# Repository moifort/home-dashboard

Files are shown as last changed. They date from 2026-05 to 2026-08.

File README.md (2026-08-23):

# Home Assistant e-Paper Dashboard

<p align="center">
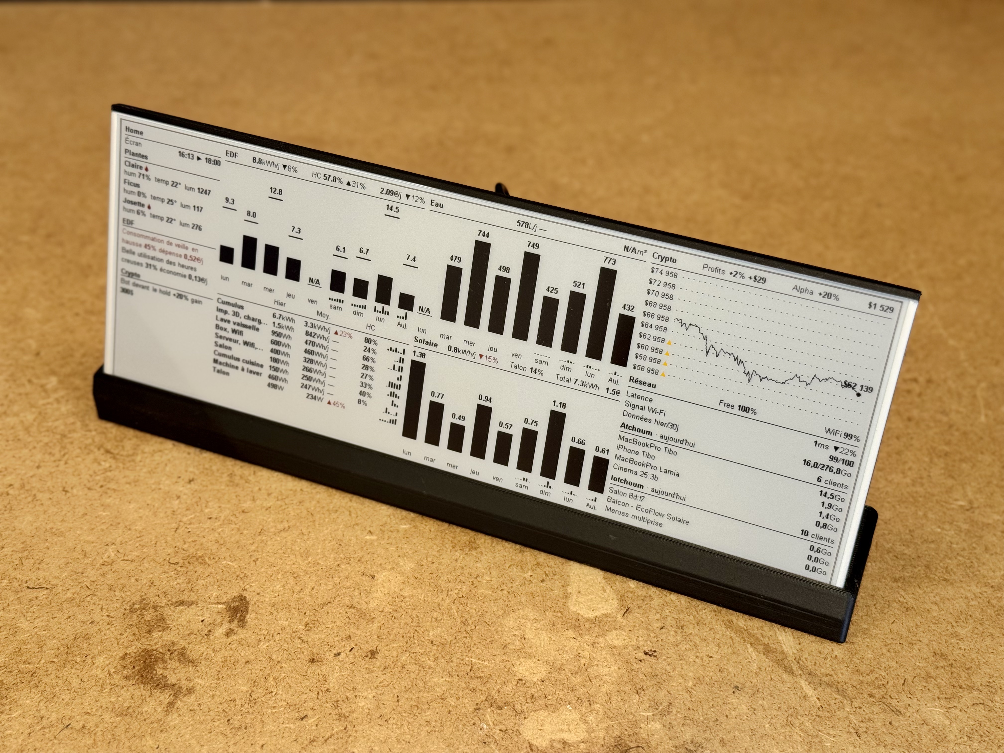
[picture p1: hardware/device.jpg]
Dashboard on its stand
  
</p>
<p align="center">
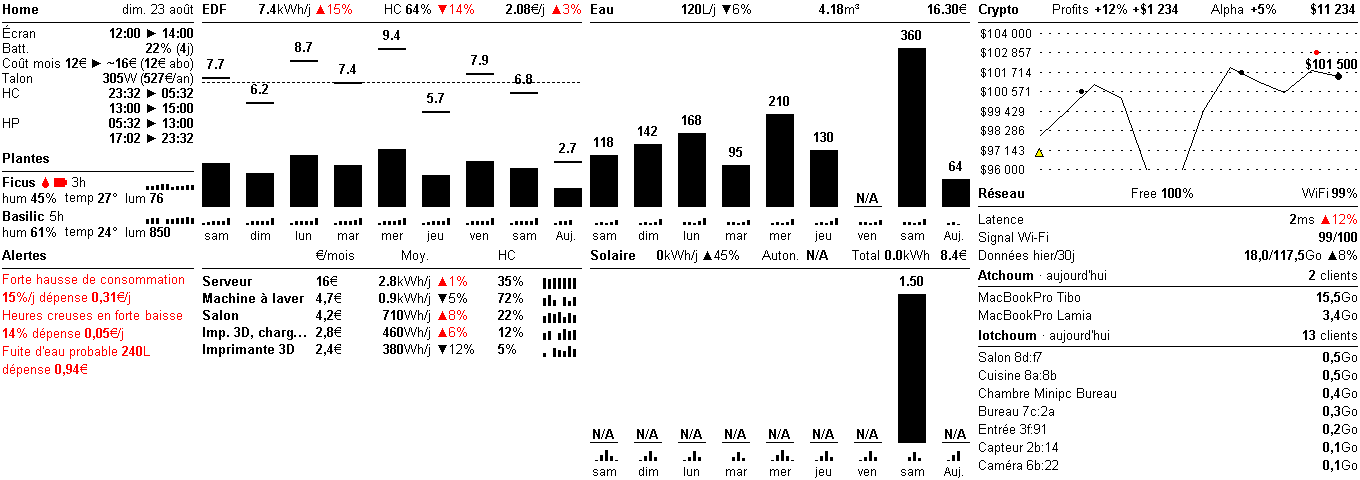
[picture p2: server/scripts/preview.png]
Dashboard preview
  
</p>

E-paper screen for the home. It reads your smart-home data and renders: electricity, solar, water, plants and network. A small ESP32 wakes on a timer, pulls the ready-made image from a server you host yourself, then goes back to sleep. No backlight, barely any power.

## Features

| Panel | What you see |
|---|---|
| **Electricity** (core) | Last 9 days + live of consumption as stacked off-peak/peak bars, with a dashed average line. Three headline stats (`kWh/j` daily average, `HC %` off-peak share, `€/j` daily cost), each with a 4-week trend. |
| **Home** | Today's date, the screen refresh schedule, the month's net home cost with its end-of-month projection and the subscription share broken out (electricity + water minus solar, `Coût mois 58€ ► ~87€ (8€ abo)`), the home's standby baseline with its yearly bill (`Talon 305W (527€/an)`), and the learned HC/HP windows. |
| **Plugs** | One row per power sensor you add (water heater, washing machine...) with its monthly cost, daily average and off-peak share. The home's permanent standby draw (talon) has its own line in the `Home` panel. |
| **Solar** | Daily solar production from an EcoFlow PowerStream: average, autonomy (share of the home's consumption the panels covered), period total and money saved. |
| **Water** | Daily water use in litres from an MQTT water meter, with month-to-date m³ and its cost. |
| **Plants** | One card per soil sensor: moisture, temperature, light, the time since its last reading, a 10-day trend on moisture data, and a water-drop icon when moisture drops below your threshold. |
| **Crypto** | A trading-bot stats banner (return %, profit, portfolio) with a price-grid snapshot: the price line over the period (cut off while the price sits outside the grid) and a dot per validated cycle, black on a win, red on a loss. |
| **Network** | UniFi internet & Wi-Fi quality, latency, data usage and top clients per network. |
| **Device battery** | Estimated charge % and days since the ESP32 was last charged, in the `Home` panel, with average/record autonomy on `/status` — inferred from the device's boot telemetry, no extra sensor. |
| **Alerts**  | Anomalies to act on, each with its € impact: consumption or standby spikes, a probable water leak, the water heater running on peak hours, a plug drifting out of off-peak, a solar disconnect, a new device on the network. Plus one event note: a broken solar production record. |

## Hardware

| Component | Reference | Price |
|---|---|---|
| e-Paper display | [Waveshare 10.85" (G) 4-color](https://www.waveshare.com/10.85inch-e-paper-hat-plus.htm) | 98,39€ |
| Microcontroller | [Seeed XIAO ESP32-S3](https://www.seeedstudio.com/XIAO-ESP32S3-p-5627.html) | 15,59€ |
| Electricity meter reader | [Lixee ZLinky_TIC V2](https://lixee.fr/fr/produits/42-zlinky-tic-v2-3770014375179.html) | 49€ |
| Power plugs | [NOUS A7Z](https://amzn.to/4evpkKK): Zigbee 16 A plug with energy monitoring (Z2M model `TS011F` / `_TZ3008_reatplte`) | 10€ |
| Plant soil sensors | [Arteco ZS-304Z](https://fr.aliexpress.com/item/1005010441104606.html): Zigbee soil sensor (moisture / temp / light) | 5€ |
| Server | Any Docker host (CasaOS, Raspberry Pi, a NAS) | – |
| 3D printed case | [Dashboard.3mf](hardware/case/Dashboard.3mf): matte PLA, 15% infill, no supports | – |

## Installation

### 1. Read your electricity meter

The dashboard reads the meter's teleinfo locally over MQTT. No cloud API, no token:

1. Plug a [Lixee ZLinky_TIC](https://lixee.fr/fr/produits/42-zlinky-tic-v2-3770014375179.html) into your Linky meter's **TIC connector** (the I1/I2 terminals under the green cover).
2. Pair it in **Zigbee2MQTT** and note its topic (e.g. `zigbee2mqtt/linky`).

It expects an HC/HP (off-peak/peak) contract. History builds up from the first connection, so a day the server is down stays blank.

### 2. Configure

```bash
cp server/.env.example server/.env
```

Required settings in `server/.env`:

```env
# The local MQTT broker Zigbee2MQTT publishes to (LAN IP, not localhost)
MQTT_HOST=192.168.1.50
MQTT_PORT=1883
MQTT_USERNAME=                       # omit if the broker is anonymous
MQTT_PASSWORD=

# The ZLinky_TIC topic in Zigbee2MQTT
LINKY_MQTT_TOPIC=zigbee2mqtt/linky

# Your contract pricing (€/kWh, €/month)
PRICE_HP=0.2065
PRICE_HC=0.1579
PRICE_ABO_MONTHLY=15.65

# Refresh schedule. The ESP32 wakes every N minutes, must match the firmware.
SCREEN_REFRESH_INTERVAL_MIN=120
```

Then add any optional panels below ([.env.example](server/.env.example) lists every variable, including the fine-tuning ones).

<details>
<summary><b>Solar (EcoFlow PowerStream)</b></summary>

Shows daily solar production above the consumption chart. The server reads the inverter's PV power from EcoFlow's app MQTT broker and integrates it into daily kWh.

```env
ECOFLOW_EMAIL=your_ecoflow_account_email
ECOFLOW_PASSWORD=your_ecoflow_account_password
ECOFLOW_DEVICE_SN=your_powerstream_serial_number
ECOFLOW_API_HOST=api-e.ecoflow.com   # EU; api.ecoflow.com (global) / api-a.ecoflow.com (asia)
```
</details>

<details>
<summary><b>Water meter</b></summary>

An ESPHome wM-Bus reader publishes the meter's cumulative index (m³) to MQTT, and the dashboard derives daily litres by index difference. Set the price to show the monthly cost.

```env
WATER_TOPIC=watermeter/index_m3        # cumulative index in m³ (raw float payload)
WATER_PRICE_M3=4.30                    # €/m³ (0 = hide cost)
```
</details>

<details>
<summary><b>Power sensors (Cumulus, washing machine)</b></summary>

Any Zigbee2MQTT / ESPHome device reporting only instantaneous power (W). Each becomes a row in the bottom table, integrated into daily kWh: what it costs per month (`€/mois`, the recent daily average priced over a mean month at its own off-peak/peak mix), its `kWh/j` daily average with a trend, its off-peak share and a 7-day sparkline. Declare them all in one variable as `topic:Display Name`, `;`-separated. Topics sharing the same label get summed into one row (e.g. every plug in a `Salon`).

```env
POWER_SENSORS=zigbee2mqtt/cumulus:Cumulus;zigbee2mqtt/washing_machine:Lave-linge
```
</details>

<details>
<summary><b>Plant soil sensors</b></summary>

Any Zigbee2MQTT soil sensor reporting `soil_moisture`, `temperature` and `illuminance`. Each becomes a `Plantes` card. The format is `topic:Display Name:threshold`, where the trailing number is the watering threshold (soil-moisture %): the water-drop icon shows when moisture drops below it. A plant without its own threshold falls back to `PLANTS_MOISTURE_THRESHOLD`. These sensors report rarely (battery), so enabling `retain` on the device in Zigbee2MQTT is recommended: a server restart then repopulates the cards immediately instead of waiting for the next wake-up.

```env
PLANTS_SENSORS=zigbee2mqtt/ficus:Ficus:30;zigbee2mqtt/basilic:Basilic:40
PLANTS_MOISTURE_THRESHOLD=30           # global fallback (%); empty = no drop without a per-plant value
```
</details>

<details>
<summary><b>Crypto-bot stats</b></summary>

Point the dashboard at your crypto-bot's GraphQL endpoint to show its trading stats top-right. Use the bot's LAN IP (not `localhost`) when both run on the same host.

```env
CRYPTO_API_URL=http://192.168.1.50:3003/graphql
CRYPTO_API_TOKEN=your_crypto_bot_api_token   # omit if no auth
```
</details>

<details>
<summary><b>UniFi network panel</b></summary>

Point the dashboard at your local UniFi gateway (UCG/UDM on UniFi OS) for a `Réseau` panel with internet & Wi-Fi quality, per-SSID client counts and top consumers. It logs in with your local gateway account. Set your SSID names so the IoT vs main split is correct.

```env
UNIFI_HOST=https://192.168.1.1
UNIFI_USERNAME=your_gateway_local_account
UNIFI_PASSWORD=your_gateway_password
UNIFI_SITE=default
UNIFI_SSID_IOT=your_iot_wifi_ssid
UNIFI_SSID_MAIN=your_main_wifi_ssid
```
</details>

<details>
<summary><b>ESP32 battery autonomy</b></summary>

The `Home` panel shows an estimated remaining charge with the days since the last charge in parens (`Batt. 22% (4j)`), with average and record autonomy on `/status`. No extra sensor: the firmware reports its boot count and reset reason on each `/display` pull, and the server bounds each charge cycle on power-on events (power restored after a recharge or a flat battery). The % is derived from the cycle timing — the longest completed run is taken as a full charge, and the share of it not yet elapsed on the current run is the charge left — so it sharpens as more cycles accumulate; until a full cycle is on record the line shows days alone (`Batt. 4j`). On by default; set `BATTERY_MONITOR=false` to disable. The autonomy is most meaningful over a full discharge cycle (charge → flat → recharge); a top-up while the device is still running leaves no power-on signal. Reflash the firmware to start sending the telemetry.

```env
BATTERY_MONITOR=true                   # set false to disable the Home battery line
```
</details>

### 3. Run the server

**Docker Compose:**

```bash
curl -O https://raw.githubusercontent.com/moifort/home-dashboard/main/server/docker-compose.yml
docker compose up -d
```

**CasaOS:** import this compose file from the CasaOS interface:

```
https://raw.githubusercontent.com/moifort/home-dashboard/main/server/docker-compose.casaos.yml
```

The dashboard is then at `http://your-server:5000`.

### 4. Flash & set up the ESP32

Requires [Arduino CLI](https://arduino.github.io/arduino-cli/) with the `esp32:esp32` core:

```bash
brew install arduino-cli
arduino-cli core install esp32:esp32

arduino-cli compile --fqbn "esp32:esp32:XIAO_ESP32S3:PSRAM=opi" hardware/esp32-display/
arduino-cli upload  --fqbn "esp32:esp32:XIAO_ESP32S3:PSRAM=opi" --port /dev/cu.usbmodem101 hardware/esp32-display/
```

On first boot, open the serial monitor and follow the prompts for Wi-Fi and the server URL:

```bash
arduino-cli monitor --port /dev/cu.usbmodem101 --config baudrate=115200
```

To reconfigure later, type `reset` within 3 seconds of boot. The ESP32 then wakes on a clock-aligned interval (`REFRESH_INTERVAL_MIN`, default 120 min), refreshes the screen, and deep-sleeps until the next boundary. A failed cycle just retries with backoff.

## Architecture

The ESP32 drives the screen and pulls a ready-made image from the server. The server does the actual work: it talks to your LAN devices and to the EcoFlow cloud for solar.

```mermaid
flowchart TD
    subgraph repo["this repo"]
        SCREEN["e-Paper screen"]:::hw
        ESP["ESP32 firmware<br/>moifort/home-dashboard"]:::mine
        SERVER["Dashboard server<br/>moifort/home-dashboard"]:::mine
    end

    SCREEN --> ESP
    ESP --> SERVER

    MOSQ["Mosquitto<br/>eclipse-mosquitto"]:::ext
    Z2M["Zigbee2MQTT<br/>Koenkk/zigbee2mqtt"]:::ext
    LINKY["Linky meter<br/>Lixee ZLinky_TIC"]:::dev
    PLUGS["Power plugs<br/>NOUS A7Z"]:::dev
    PLANTS["Plant soil sensors<br/>Arteco ZS-304Z"]:::dev
    WATER["Water meter<br/>moifort/watermeter"]:::mine

    SERVER --> MOSQ
    MOSQ --> Z2M
    MOSQ --> WATER
    Z2M --> LINKY
    Z2M --> PLUGS
    Z2M --> PLANTS

    ECO["EcoFlow cloud<br/>app API + MQTT"]:::ext
    PV["Solar · PowerStream"]:::dev
    SERVER --> ECO
    ECO --> PV

    CRYPTO["Crypto trading bot<br/>GraphQL"]:::mine
    UNIFI["UniFi gateway"]:::ext
    SERVER --> CRYPTO
    SERVER --> UNIFI

    classDef mine fill:#d4ecff,stroke:#0a6ebd,color:#062a44;
    classDef ext  fill:#eeeeee,stroke:#999999,color:#222222;
    classDef dev  fill:#ffffff,stroke:#bbbbbb,color:#222222;
    classDef hw   fill:#fff4cc,stroke:#caa300,color:#3a3000;

    click ESP "https://github.com/moifort/home-dashboard" _blank
    click SERVER "https://github.com/moifort/home-dashboard" _blank
    click WATER "https://github.com/moifort/watermeter" _blank
    click MOSQ "https://github.com/eclipse/mosquitto" _blank
    click Z2M "https://github.com/Koenkk/zigbee2mqtt" _blank
```

## Endpoints

| Method | Path | Description |
|---|---|---|
| `GET` | `/display` | EPD binary buffer (163,200 bytes), rendered fresh, for the ESP32 (also records the device's battery telemetry from its query params) |
| `GET` | `/` | Auto-refreshing HTML preview in a browser |
| `GET` | `/preview.png` | The dashboard rendered as a PNG |
| `GET` | `/status` | Server status as JSON (last render, day count, per-domain config) |
| `GET` | `/api/data` | The full render data as JSON (debug) |

## License

DWTFYW

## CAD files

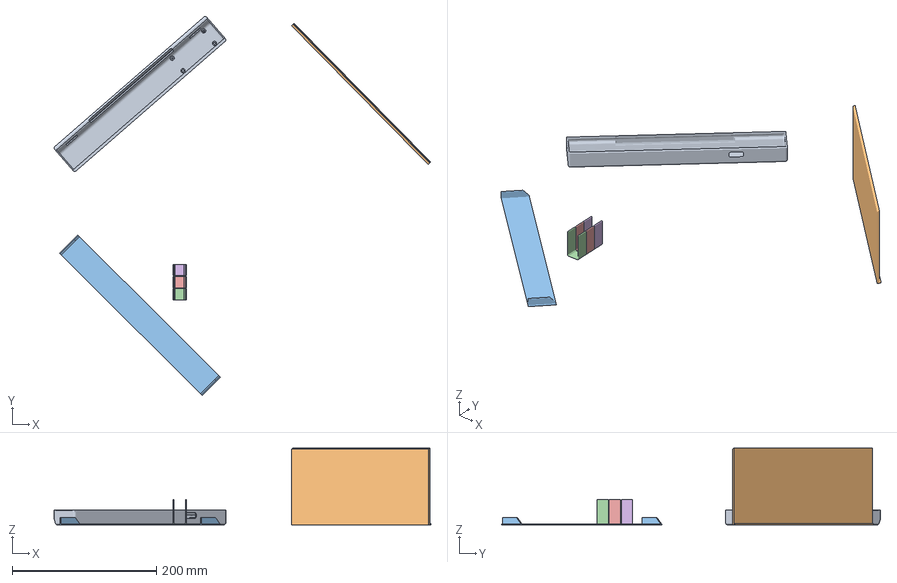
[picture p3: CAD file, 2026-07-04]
hardware/case/Dashboard.3mf
523.1 x 526.3 x 106.7 mm
bottom_holder.STL
screen_support.STL
Bottom-Cover.STL
Blank 6U.stl x 3

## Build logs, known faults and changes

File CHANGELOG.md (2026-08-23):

# Changelog

## 2026-08-23

- **Crypto grid: the price line stops at the grid bounds, and validated cycles are plotted**: a price leaving the grid was clamped onto the nearest bound, so a stretch spent below the grid drew as a flat line glued to the bottom axis — read as a $0 price for the whole period. The series is now cut on the bound (linear interpolation on the crossing) and the out-of-band part is simply not drawn, leaving a gap that says "the price left the grid"; the `now` marker keeps its clamped position, parked under its price label, which is exactly what shows the price is out of bounds. On top of that, every **validated cycle** (a completed round-trip) now gets a dot on the chart, placed on the leg executed last (a cycle opened by an inventory sell closes on its buy-back) — black for a winning cycle, red for a losing one, mirroring the iOS `GridSnapshotCard`. The grid query pulls `trades(limit: 100)`; cycles outside the displayed window or outside the grid bounds are dropped like the line. Goldens re-baselined, preview regenerated; no new environment variable.

## 2026-08-18

- **`Home`: the talon replaces the two live lines**: the panel's `Conso 850W (HP)` and `Solaire 320W` lines showed the instantaneous draw at the moment of the render — a number already stale by the time the e-paper refreshes, and the one figure nobody can act on. They are gone; in their place a single `Talon 305W (527€/an)` line pairs the recent daily average standby draw with what it costs over a year (8h HC + 16h HP blend), i.e. the money actually worth chasing. The `Talon` row disappears from the bottom table, which is now strictly one row per power sensor. The domains' `live_power()` helpers stay in place, simply unused by the render. Goldens re-baselined, preview regenerated; no new environment variable.
- **`Réseau`: the IoT SSID shows a seventh client**: the last mini-table (the IoT network, `Iotchoum`) was capped at six clients and still left a sliver of empty screen under it. It now lists up to seven, which needed 6px back from the panel's internal spacing (the gap under the usage row, under each section separator and between the two sections) — the last row now ends 5px above the screen edge instead of overflowing it. The main Wi-Fi keeps its top-5 and the bottom guard still prevents overflow. Goldens re-baselined, preview regenerated; no new environment variable.
- **Bottom table: the `Hier` (yesterday) column becomes `€/mois`**: each plug row (and `Talon`) opened on yesterday's kWh — a single noisy day, already readable in the row's sparkline. It now shows what the row costs per month: the recent 9-day daily average priced over a mean calendar month (30.44 d) at the meter's own tariffs, split at the group's measured off-peak share (`PRICE_HC`/`PRICE_HP`); with no HC history yet, everything is priced at the peak rate. `Talon` reuses its yearly estimate divided by 12. Amounts read with one decimal below 10 € (`2,4€`) and whole euros above (`16€`). Yesterday's figure stays in the data (it still feeds the alerts). Goldens re-baselined, preview regenerated; no new environment variable.

## 2026-07-12

- **`Home`: the subscription share is broken out of the month cost**: the `Coût mois` line hid the fixed part inside its total; it now reads `58€ ► ~87€ (8€ abo)`, surfacing the electricity subscription accrued so far this month (`PRICE_ABO_MONTHLY` prorated over the elapsed days, the same basis as the total). It stays a single line at the panel width, number bold and the rest regular. Goldens re-baselined, preview regenerated; no new environment variable.
- **`Réseau`: the IoT SSID shows a sixth client**: the panel's last mini-table (the IoT network, `Iotchoum`) was capped at its five busiest clients, leaving the bottom of the screen empty when the main Wi-Fi is light. It now lists up to six, filling the gutter down to the screen edge (the main Wi-Fi keeps its top-5, and the existing bottom guard still prevents overflow). Goldens re-baselined, preview regenerated; no new environment variable.

## 2026-07-04

- **`EDF`/`Eau`/`Solaire`: the weekend day-label underline is gone**: the `sam`/`dim` labels no longer carry the 1px underline added in the glanceability pass. It read as an unexplained mark under every weekend column without earning its ink, so it was dropped from all three charts (the `_underline_weekend` helper is removed). Render golden re-baselined, preview regenerated; no new environment variable.
- **`Alertes`: the overflow row spells itself out**: the truncation indicator was a bare bold `+N`, which gave no clue what it counted. It now reads `+N autre alerte` / `+N autres alertes` (the number bold, the rest regular, still a single line at the panel width), so a truncated board says plainly how many more alerts are hidden. No new environment variable; goldens unchanged (the fixture does not overflow).

- **`Home`: net month cost with an end-of-month projection**: a new `Coût mois 58€ ► ~87€` line consolidates the euros previously scattered across three panels into the one figure that matters: what the home costs this month, net (grid electricity at HC/HP prices + prorated subscription + water, minus solar savings). The projection extrapolates complete days only (a partial today would drag it down) and hides on the 1st of the month. Composed from the month figures each enabled domain attaches, so a disabled domain simply contributes nothing. Goldens re-baselined; no new environment variable.
- **`Home`: live snapshot lines**: the screen was entirely historical; the panel now shows `Conso 850W (HP)` (the meter's instantaneous draw + the current tariff period, straight from the live PTEC) and `Solaire 320W` (the inverter's last heartbeat). A line hides when its source has no sample fresher than 15 minutes, so a dead stream never shows stale watts. The values are as of the render, i.e. the device's last wake. No new environment variable; goldens unchanged.
- **`Solaire`: autonomy replaces the talon-coverage ratio**: the banner now shows `Auton. 42%`, the share of the home's total consumption the panels covered (PV / (grid + PV), on the complete days both charts share; model: all PV self-consumed, as there is no export measurement). The old `Talon 111%` only related production to the night base load and is gone (the talon keeps its own bottom-table row). Goldens re-baselined.
- **Alerts: anomalies only, plus three new rules**: the positive notes that restated visible panels are gone ("belle baisse de consommation", "belle utilisation des heures creuses", standby/cumulus drops, "forte production solaire", both crypto vs-hold notes: the trends and the Alpha figure already show all of them, in red when bad). The board is now a to-act list. Three rules land in their place: **`Cumulus chauffé en heures pleines`** (the water heater put 30%+ of yesterday's energy on peak hours: stuck contactor, drifted clock; costed at the HC to HP premium), **`Record de production solaire`** (yesterday beat every recorded day, needs 14 days of history: an event, so it stays), and **`Nouvel appareil`** (a never-seen client MAC joined the network in the last 24h, backed by a new `known_clients` table; the first run seeds silently so a fresh deploy does not flag the whole home). Goldens re-baselined; no new environment variable.
- **Six glanceability wins across the panels**: the `Home` title band shows today's date (`ven. 3 juil.`, the screen's only date, so a stale render is immediately visible); `sam`/`dim` day labels are underlined on the three charts; a dashed average line crosses the `EDF`/`Eau`/`Solaire` charts so each day reads above/below normal at a glance; power sensors with no recent data disappear from the bottom table instead of rendering a row of em dashes; the `Talon` row prices the standby waste per year (`Talon 527€/an`, 8h HC + 16h HP blend); and the Crypto/Réseau divider moves up 32px, compacting the trading grid and giving the `Réseau` panel top-5 clients per network instead of top-4. Goldens re-baselined, preview regenerated; no new environment variable.
- **Panel titles stay at the uniform 13px bold**: an earlier experiment gave every panel title (`EDF`, `Eau`, `Solaire`, `Crypto`, `Réseau`, `Home`, `Plantes`, `Alertes`) a dedicated 16px bold scale; it was reverted. Titles go back to the same 13px bold as the values, the sections read cleanly at one size, and the banner code drops the mixed-size baseline-alignment machinery (the `Réseau` separator keeps the shared `_title_sep_y` metric). Goldens re-baselined, preview regenerated; no new environment variable.
- **`Alertes`: overflowing items are summarised by a `+N` row**: when the left gutter runs out of room the panel used to drop the remaining alerts silently — nothing indicated more were active. Only items that fit entirely are now drawn, and the rest collapse into one bold `+N` line, so a busy board always tells you it is truncated. Goldens re-baselined; no new environment variable.
- **Crypto grid: the yellow skip marker is outlined in black**: the ▲ flagging a skipped grid level was drawn as flat yellow on white — the exact low-contrast case the e-paper rules forbid, nearly invisible on the panel. It now carries the 1px black outline its own docstring always promised. Goldens re-baselined.
- **Fix: battery charge % no longer corrupted by USB power blips**: any reset other than a deep-sleep wake (a USB host cutting power, a re-flash) opened a new battery "cycle"; a minutes-long spurious run dragged the average autonomy down and could even become the *record* — the 100% reference of the charge estimate — making a full battery read an arbitrarily low %. Completed cycles shorter than **2 days** are now excluded from the average, record and estimate (covered by new unit tests). No new environment variable; goldens unchanged.
- **Fix: a same-day Linky catch-up after an MQTT outage is no longer discarded**: the 15 kWh plausibility cap on a single index step also rejected the perfectly legitimate first frame after hours of broker downtime (e.g. 8h at 3 kW ≈ 24 kWh), silently under-counting the day. The cap now scales with the elapsed time since the previous frame (12 kW of subscribed power), so long-gap catch-ups count while a 16 kWh jump in one minute is still rejected. No new environment variable; goldens unchanged.
- **Reliability: SQLite in WAL mode + two race fixes**: the store now opens in WAL with a busy timeout, letting the ~6 MQTT writer threads and the HTTP render thread proceed concurrently instead of risking a swallowed `database is locked` (a silently lost 30s persist). The `Home` tariff windows are snapshotted before crossing from the linky thread to the render thread (a mid-iteration append could 503 a `/display` pull), and the whole per-domain telemetry hook is guarded so a failing integration can't kill the pull. No new environment variable; goldens unchanged.
- **Faster `/display`: the EPD converter is vectorized**: the 4-color quantizer walked all 652,800 pixels in pure Python on every pull; it now runs as numpy masks + vectorized bit-packing (~8 ms), with byte-identical output (proven by the render golden and a new converter test against the scalar reference). No new environment variable.
- **Internal: large deduplication pass, behaviour-preserving**: the four plain-broker MQTT listeners share one `MqttListener` base, solar and the power plugs share one watts→daily-Wh integrator, the repositories share a `transaction()` context manager, sensor-declaration parsing (`POWER_SENSORS`/`PLANTS_SENSORS`) and the 30-min slot helpers are unified in `module/`, the `power` sub-domain is split into command/query like its siblings, and the renderer's repeated layout constants/closures are named module helpers. Both goldens stayed byte-identical through the whole pass (a malformed price env var now also falls back to its default instead of crashing the import).

## 2026-06-15

- **`Home`: battery line now shows an estimated charge %**: building on the autonomy tracking, the `Batt.` line adds an estimated remaining charge derived from the recorded cycle timing — no extra sensor. The longest completed run is taken as a full charge (100%), and the share of it not yet elapsed on the current run is the remaining charge, so the line reads `Batt. 22% (4j)` (% as the main figure, days since charge in parens). The estimate sharpens as more cycles accumulate; until at least one full cycle is on record it falls back to days alone (`Batt. 4j`). A run outlasting the record reads `0%` (living on borrowed time). Also exposed as `battery_percent` on `/status`. Data and render goldens re-baselined, preview regenerated; no new environment variable.

## 2026-06-14

- **`Alertes`: all alerts under a single section header**: the left-gutter status board used to give every active domain (`EDF`, `Eau`, `Solaire`, `Crypto`…) its own bold title and 1px separator, so a few alerts across domains burned a lot of vertical space in section headers alone. The active items are now listed under one `Alertes` (Alerts) header, in the same order (most problems first, problems in red before positive notes in black) — the per-domain titles are gone, freeing room to show more lines. The messages already name what they flag, so no domain label is needed. Render golden re-baselined, preview regenerated; no new environment variable.
- **`Home`: ESP32 battery autonomy — days since the last charge**: the dashboard now tracks how long the device runs on a charge, with no extra sensor. The firmware reports its boot count and reset reason as query params on the `/display` pull; the server logs each pull into battery cycles (a run on one charge, bounded by power-on events — power restored after a recharge or a flat battery) and shows a `Batt.` line in the `Home` panel (`4j` = days since the last charge). Average and record autonomy, plus the last telemetry, are exposed on `/status`. A new optional variable **`BATTERY_MONITOR`** (default `true`; set `false` to disable) gates it. Caveat: the autonomy is most meaningful over a full discharge cycle (charge → flat → recharge); a proactive top-up while the device is still alive leaves no power-on signal. Data and render goldens re-baselined. **Reflash the firmware** to start sending the telemetry (backward compatible: an un-flashed firmware sends nothing and the tracking simply stays empty).

## 2026-06-13

- **`Plantes`: cards show how long since the last reading, with a longer moisture trend**: each card's title line now carries a compact "time ago" label (`3h`, `12min`, `2j`) glued to the right of the plant's name, so you can tell at a glance how fresh the reading is (these sensors report only 1-2 times a day). It is computed from the last stored reading's timestamp, so it survives a restart. The moisture sparkline also grew from 7 to 10 days. Render and data goldens re-baselined, preview regenerated; no new environment variable.

## 2026-06-12

- **Fix: MQTT listeners reconnect after a lost connection**: paho's manual `loop()` never reconnects by itself; it just returns an error code, which every listener ignored. The first broker hiccup (restart, network blip, missed keepalive) silently turned a listener into a zombie: thread alive, subscribed to nothing, spinning on a dead socket until the next deploy. Most visible on the `Plantes` cards (a soil sensor reports only 1-2 times a day, so one missed report meant a whole day of em dashes), but the Linky, water, power-plug and solar listeners were equally affected. All five now share a single network-loop pump (`module/mqtt.py`) that turns a failed loop into an exception and falls back to the existing retry path: fresh connect, resubscribe, and a "retrying in 60s" log line instead of silence. No new environment variable; goldens unchanged.
- **`Plantes`: cards keep the last known reading instead of dashing out at midnight**: each card read only the current calendar day's stored row, so at midnight every metric reset to em dashes until the sensor's next report, often most of the morning. A soil reading is a slowly-moving state: the card now shows the freshest stored value of each metric within a 2-day lookback, so a plant that last reported yesterday evening keeps its values on screen overnight. A sensor silent for 3+ days still dashes out (the signal a probe is dead). Tip: enable `retain` on the sensor's topic in Zigbee2MQTT and a server redeploy repopulates the cards immediately instead of waiting for the next wake-up. No new environment variable; goldens unchanged.

## 2026-06-10

- **Fix: `Plantes` moisture sparkline always read full**: the 7-day soil-moisture bars were normalised to each plant's own weekly max, so a near-flat week (or a bone-dry plant whose best day was 5%) always drew full-height bars. Moisture is an absolute percentage: the bars now scale to the **0-100% range** (clamped), keeping the 1px tick for a real 0% day and the gap for days with no reading. The kWh sparklines of the bottom table keep their relative scale (no absolute ceiling there). Render golden re-baselined, preview regenerated; no new environment variable.
- **Sparklines and intraday strips: zeros leave a gap again**: every zero value (and quiet intraday slot) drew a 1px floor tick, which read as noise on the bottom-table sparklines and the `EDF`/`Eau`/`Solaire` strips. A zero or missing bucket now leaves a gap; the `Plantes` moisture sparkline is intentionally untouched (a 0% there is a real bone-dry reading, not missing data). Render golden re-baselined, preview regenerated; no new environment variable.
- **Fix (firmware): a stalled `/display` download no longer freezes the device**: if the server died mid-response (connection open, no more bytes), the firmware's read loop spun forever and the screen stayed frozen with WiFi up until a power cycle. The body read now has a hard **60s deadline** (`FETCH_DEADLINE_MS`) and falls back to the existing retry/deep-sleep path. Reflash the firmware to pick it up.
- **Fix (server): a silent client can no longer block the server**: the HTTP server is single-threaded and had no socket timeout, so one client opening a connection without ever sending its request (or dying mid-read) blocked every further ESP32 pull. Idle connections are now dropped after **60s**; `/status` and `/api/data` also gained the `Content-Length` header the other endpoints already sent. No new environment variable.
- **Fix: bottom-table edge case showed `1000 Wh` instead of `1.0 kWh`**: a daily value between 0.9995 and 0.9999 kWh rounded its Wh display up to 1000 without switching units. The unit now flips on the rounded value. Goldens unchanged.

- **`Home`: HC/HP tariff windows survive a restart** — the off-peak/peak windows shown under `Écran` are learned live from the meter's `PTEC` transitions, but were kept **in RAM only** — so every redeploy (Watchtower) blanked them until new transitions re-learned the full day, up to ~24h of an empty tariff list. They are now **persisted to the local store** (a new `tariff_windows` table) at each transition and **reloaded on startup**, so the panel shows yesterday's windows right away and fills in today's as they complete. The day's two off-peak + two peak windows (plus the in-progress one) all round-trip; the current period is restored too, so the off-peak split is right from the first moment after a restart. No new environment variable; goldens unchanged.
- **Left gutter: section titles match the chart sections' height** — `Home`, `Plantes` and the `Alertes` sub-sections used a tighter title-to-separator gap than the chart panels (`EDF`, `Eau`, `Solaire`…), so their title bands read as slightly shorter. They now use the **same gap (`+8`)** as the chart sections, so every section title sits the same height across the whole dashboard. Render golden re-baselined, preview regenerated; no new environment variable.
- **`Plantes`: watering drop now driven by a configurable moisture threshold (env change)** — the red water-drop next to a plant's name used to follow the device's own `water_warning` flag, which is fiddly to configure and unreliable. It now appears purely when the plant's **soil moisture falls below a threshold you set**. Each `PLANTS_SENSORS` entry takes an optional trailing numeric segment — `topic:Display Name:threshold` (soil-moisture %); a plant without its own falls back to the new global **`PLANTS_MOISTURE_THRESHOLD`**, and with neither it never shows a drop. The non-numeric last segment of a label is still treated as text, so colons in names keep working. `water_warning` is no longer parsed, stored or read (a legacy DB column is left untouched); the low-battery icon (`battery_state`) is unchanged. Goldens unchanged. **On CasaOS: add a `:threshold` to your `PLANTS_SENSORS` entries and/or set `PLANTS_MOISTURE_THRESHOLD`, else no plant will flag for watering.**
- **`Plantes`: smaller, baseline-aligned watering drop** — the red water-drop flag next to a plant's name spanned the full line height (descender included) and read as oversized; it now matches the name's cap height and rests its bottom on the text baseline, like a letter. Render golden re-baselined, preview regenerated; no new environment variable.
- **⚠️ `HC_WINDOWS` removed — off-peak now follows the live `PTEC` only (env change)** — the off-peak/peak split (the power sensors' `HC` column, the integrator) no longer falls back to a configurable clock. The meter is the source of truth: `is_off_peak` reads the **last `PTEC` seen on the ZLinky, trusted regardless of age** — an HC/HP period lasts hours, so the last reading stays the best estimate even when the teleinfo goes briefly quiet, and it never breaks if the contract windows change (the reason we moved to `PTEC`). Before the very first frame after a start — the only moment no period is known — it reports peak, so the split never over-counts on a cold start. The `HC_WINDOWS` clock fallback, its parse and the `hc_windows` field of `/status` are gone. Goldens unchanged (no render/data change). **On CasaOS: remove the `HC_WINDOWS` variable (harmless if left, simply ignored).**
- **Server renders fresh on every pull — the hourly render cache is gone** — every `/display` (and `/preview.png`, `/api/data`) now builds the dashboard **fresh from the local SQLite store** and renders on demand, instead of serving an hourly in-memory snapshot. Since reads are local and instantaneous there was nothing to cache, and the snapshot only made the screen lag the data — most visibly the `Plantes` panel, which showed a stale (often empty) reading until the next hourly build. A build/render failure now returns **503** (the ESP32 keeps its image and retries at its next wake) rather than serving a stale buffer. The `dashboard_data`/`epd_buffer` caches, the hourly refresh loop and the **`POST /refresh`** endpoint are removed; `/status` stays a cheap, network-free healthcheck. Goldens unchanged; no new environment variable.
- **`Alertes`: quiet domains are hidden** — the status board no longer prints a *Rien à signaler* (nothing to report) row for a domain that has nothing to flag; it now lists **only the domains with active alerts**, most problems first then by severity. When every monitored domain is quiet the panel falls back to a single *Tout va bien* (all good) section. Frees vertical space in the left gutter. Goldens re-baselined, preview regenerated; no new environment variable.
- **Left gutter: tighter vertical rhythm** — the `Home` / `Plantes` / `Alertes` sections packed too airily; the per-section header padding (title→separator, separator→content), the gap between alert sub-sections and the gaps between the stacked panels are all trimmed a few pixels so the column fits more without losing legibility. Render golden + preview regenerated; no new environment variable.
- **New `Plantes` (Plants) panel — Zigbee soil sensors** — a new optional domain shows your plants in the left gutter, stacked under `Home`. Any Zigbee2MQTT soil sensor reporting `soil_moisture` / `temperature` / `illuminance` (plus `water_warning` / `battery_state` on supported devices) is declared in **one variable** `PLANTS_SENSORS` (`;`-separated `topic:Display Name`) and rendered as a two-line card: line 1 is the name with a red **water-drop** icon when it needs watering and a red **battery** icon when its battery is low, plus a 7-day soil-moisture sparkline; line 2 is `hum 45%  temp 27°  lum 76`. Watering comes from the device's `water_warning`; the low-battery flag from `battery_state`. Readings are instantaneous states (the day's latest value is kept, no integration, no backfill); the listener is subscribe-only so battery sensors aren't polled. The gutter sections (`Home` → `Plantes` → `Alertes`) were also tightened to pack closer. New env var **`PLANTS_SENSORS`** (empty = off); goldens (data + render) and preview regenerated.
- **`Home`: tariff lines show every HC/HP window, grouped** — the panel kept only the *last* completed window per period (one `HC` + one `HP` line); it now keeps the **last two windows of each period** and renders them all, **grouped HC lines then HP**, with the period label (`HC`/`HP`) printed **once per group** (the second window of a group is left unlabeled) — e.g. `HC 23:32 ► 05:32` / `   13:00 ► 15:00` / `HP 05:32 ► 13:00` / `   17:02 ► 23:32`. The day has two off-peak and two peak windows, so once all four have been observed live (via the ZLinky's `PTEC` transitions, same as before) the full day is shown; after a restart the panel fills up window by window over the day. Goldens re-baselined, preview regenerated; no new environment variable.

## 2026-06-08

- **`Home`: tariff lines show HC/HP windows as ranges** — the single "last switch per period" line (`HC 15:02   HP 05:32`) is replaced by **two lines, one per period**, each showing that period's last completed window as `HH:MM ► HH:MM` (same arrow style as the `Écran` schedule line) — e.g. `HC 13:00 ► 15:00` / `HP 05:32 ► 13:00`. Windows are learned **live** from the meter's `PTEC` transitions: a window is recorded when the transition that *ends* it arrives, so a multi-window-per-day off-peak schedule renders correctly **without relying on the `HC_WINDOWS` config**. Each period's line stays absent until one of its windows has completed since startup (after a restart: blank → one line → both, a few hours each step); the period currently in effect shows its last *completed* window since the in-progress one has no end yet. Goldens re-baselined, preview regenerated; no new environment variable.

## 2026-06-07

- **`Home`: tariff line shows both last switches** — the line gains the other period's last switch, current period always first: `HC 15:02   HP 05:32` (off-peak since 15:02, the last peak period had started at 05:32) instead of `HC depuis 13:00`. Both times are real HC↔HP transitions observed live on the ZLinky's `PTEC`; the right side stays empty until the other period's own switch has been seen (so after a restart the line goes absent → current only → complete, at most a few hours each step). Goldens re-baselined, preview regenerated; no new environment variable.

- **Fix: `Home` tariff-period line never reached the screen** — the `HC depuis 13:00` line shipped on 2026-06-07 was attached by the hourly data build, but the `/display` pull re-render (the buffer the panel actually shows) rebuilt the `Home` dict from scratch to refresh the displayed pull time — wiping the tariff key on every ESP32 pull. The pull path now rebuilds `Home` through a shared helper that re-attaches the **live** tariff state, so the line shows as soon as a real HC↔HP transition has been observed (restart semantics unchanged). Covered by two new regression tests; goldens byte-identical, no rendering change, no new environment variable.

- **Intraday strips: zero ticks for quiet slots** — in the mini bar-graphs under the `EDF`, `Eau` (Water) and `Solaire` (Solar) daily bars, a 4h bucket with no sample now draws the same thin **1px tick** as a real zero instead of leaving a hole: a silent water meter or a PV inverter asleep at night reads as *zero consumption/production*, not missing data. Only today's buckets **after the last sample** (not elapsed yet) keep their gap, so the `Auj.` (today) strip still stops at the current time; a day with no sample at all still shows no strip (no backfill). Render golden byte-identical (the frozen fixture has no quiet slots); preview regenerated; no new environment variable.
- **`Home`: tariff-period line** — a second line under `Écran` shows the current pricing period and the exact time the meter switched to it, e.g. `HC depuis 13:00` (off-peak since 13:00). Unlike the removed EDF title dot (stale by design between refreshes), this reads as a fact: the **wall-clock moment of the last HC↔HP transition** observed live on the ZLinky's `PTEC` field. The first frame after a server start only baselines the period (not a switch), so the line stays **absent until a real transition is seen** — no `HC_WINDOWS` clock guess, no DB persistence; a restart blanks it until the next flip (at most a few hours). Goldens and preview regenerated; no new environment variable.

## 2026-06-06

- **`EDF`: tariff-period dot removed** — the live HC/HP dot after the `EDF` title is gone. The pricing period flips on a sub-hour schedule while the screen only refreshes every few hours, so the dot was stale most of the time and conveyed nothing reliable. Removes the dot rendering plus the `off_peak_now` plumbing (the off-peak detection itself stays — the power sensors' HC split relies on it). Goldens and preview regenerated; no environment variable change.
- **`Eau` & `Solaire` charts: intraday strips** — the Water and Solar charts gain the same mini bar-graph under each daily bar as the EDF chart (6 four-hour sparkline-style bars between the bar and its day label, space always reserved). Neither domain stored sub-daily data, so each gains its own samples table filled live: **`solar_samples`** keeps the inverter heartbeats' mean PV watts per 30-min slot (flushed at slot boundaries, like the TIC), **`water_samples`** keeps the meter's cumulative index per slot, diffed into litres at read time (midnight baseline from the previous day, quiet-slot jumps land on the next reporting slot, meter resets re-baseline silently). Buckets average the power profiles but **sum** the litres; each chart has its own fixed Y ceiling — `INTRADAY_SOLAR_MAX_W` (default **800** W, the PowerStream cap) and `INTRADAY_WATER_MAX_L` (default **150** L per 4h bucket), peaks clip. **No backfill**: strips accumulate day by day from deployment; today's fills live. Also fixes the water MQTT docstring (the meter reports every ≤30 min, not "a few frames per day"). Goldens (data + render) and preview regenerated.

- **`EDF` intraday strip: fixed Y scale (`INTRADAY_MAX_W`)** — the strips' heights no longer normalise to the 9-day window's max (which re-dilated the whole scale whenever a peak day slid out of the window) but to a **fixed absolute ceiling**, the new `INTRADAY_MAX_W` env var (default **3000** W of mean `PAPP` at full height). Day profiles now compare across renders, not just within one; a 4h mean above the ceiling clips to the strip's full height. Render golden and preview regenerated.
- **`EDF` intraday strip: sparkline-style bars** — the intraday profile under each bar drops its 28 thin 1px columns (hard to read on e-paper) for **6 four-hour bars** drawn with the bottom-table sparkline geometry (3px bars, 2px gaps — exactly the bar's 28px width). Heights still normalise to the 9-day window's global max, now computed on the **bucketed 4h means** so the window's tallest bar reaches the strip's full height; a bucket with no sample still leaves a gap (today's strip keeps filling live, bar by bar). Render golden and preview regenerated; no new environment variable.
- **`EDF` chart: intraday power profile under each bar** — each daily bar gains a **bar-wide (28px) mini bar-graph** squeezed between the bars' baseline and the day labels, showing *how* that day's power was drawn: the mean apparent power (`PAPP`) of each 30-min slot (the ZLinky's `tic_samples`), resampled to one 1px column per pixel. Heights normalise to the **9-day window's global max** so day profiles compare to each other — the night talon reads as a thin baseline, the cumulus/oven as spikes. Today's strip **fills live** through the day; a slot with no sample leaves a gap, and there is **no backfill** — days recorded before the ZLinky was connected show no strip, so the strips accumulate day by day from deployment. The bars give up ~18px of max height; the strip space is always reserved so the layout never jumps. Also fixes the preview script's EDF demo-week injection, dead since the calendar-anchored window (the dev DB's empty history rendered as 9 N/A columns). Goldens (data + render) and preview regenerated; no new environment variable.
- **Fix: `EDF` chart window anchored on the calendar** — the chart used to show the last 8 *rows present in the database*, so a missing day (server down, data purged) silently shifted the window one day back (the chart ended on Thursday with no trace of the absent Friday). `build_core` now walks the **8 calendar days before today** and fills holes with an empty row, which renders as the existing **N/A column marker** — a gap now reads as a gap. Goldens byte-identical (the test fixture has no hole); no new environment variable.

## 2026-06-05

- **`EDF` chart: live `Auj.` (today) bar** — now that the ZLinky integrates the meter indexes since midnight, the consumption chart shows the **last 8 complete days + today's partial bar**, which grows through the day like the `Eau` (Water) and `Solaire` (Solar) charts (the old REST API had no same-day data). The stats banner, the `Talon` and the alerts keep computing over **complete days only** — a partial day would drag the averages down. Goldens and preview regenerated; no new environment variable.
- **Fix: tariff dot drawn as a real circle** — the dot after the `EDF` title was the Arial `●` glyph, small and lumpy after the e-paper thresholding; it is now a true 10px circle (rasterised 4x oversize, downscaled, re-thresholded) centered on the banner's cap height. Render golden and preview regenerated.
- **`EDF`: live tariff-period dot** — a filled dot right after the `EDF` banner title shows the meter's current pricing period: **red = peak hours** (HP, expensive), **black = off-peak** (HC). Driven by the ZLinky's live `PTEC` field (with the `HC_WINDOWS` clock as fallback) and recomputed at **every `/display` pull**, so it reads the exact moment the screen refreshed — then holds until the next refresh. No new environment variable; goldens and preview regenerated.
- **Whole-percent trends everywhere** — every trend on the dashboard (`EDF` stats, `Talon`, power sensors, `Solaire`, `Eau`, `Réseau`) now rounds to a **whole percent** at computation (no more `▼6.5%`); the alert figures inherit the integer values. A sub-0.5% drift rounds to 0 and renders as the em dash (no trend). Goldens regenerated.
- **Bottom table: names truncate at 15 characters** (was 13) — `Machine à laver` now fits in full; longer labels keep the ellipsis (e.g. `Imp. 3D, charg…`, exercised by a new preview demo row). Render golden and preview regenerated.
- **Fix: ZLinky payload parsing** — Zigbee2MQTT translates the TIC labels to snake_case property names (`HCHC` → `current_tier1_summ_delivered`, `HCHP` → `current_tier2_summ_delivered`, `PAPP` → `apparent_power`, `PTEC` → `tariff_period`), so every frame failed the parser and `last_linky_message` stayed empty. The parser now reads the translated names (raw uppercase labels kept as fallback) and takes the live period from `tariff_period` — `current_tarif` is the OPTARIF contract constant, not the current period. Pinned on a payload captured from the live device.

- **⚠️ Linky data now read locally from a Lixee ZLinky_TIC over MQTT (breaking env change)** — the `EDF` consumption data no longer comes from the conso.boris.sh REST API but from a **ZLinky_TIC** Zigbee dongle plugged into the meter's TIC connector and published by Zigbee2MQTT (`LINKY_MQTT_TOPIC`, default `zigbee2mqtt/linky`, over the shared `MQTT_*` broker). Daily HC/HP kWh are now **exact** — computed as the deltas of the meter's cumulative `HCHC`/`HCHP` indexes since midnight (guarded against index resets and implausible jumps), instead of summing a 30-min load curve. A new **`tic_samples`** table keeps a fine-grained history (one row per 30-min slot: index snapshot + mean apparent power `PAPP`, unlimited retention); the **`Talon`** keeps its exact semantics (P20 of the night 23h–05h samples) but is now recomputed from those persisted slots, so a server restart no longer loses the night. The **off-peak split everywhere now follows the meter itself**: the live `PTEC` field ("HC.."/"HP..") decides whether a power sensor's increment counts as off-peak, with the `HC_WINDOWS` clock as fallback when the teleinfo goes quiet (>15 min) — so the `HC` column tracks what the meter actually billed, even if the contract windows change. There is **no backfill**: a day with the server down stays blank. Render layout and goldens are byte-identical. **On CasaOS: remove `LINKY_TOKEN` and `LINKY_PRM`; `MQTT_HOST` must be set (it now also feeds the core); add `LINKY_MQTT_TOPIC` only if your topic differs from `zigbee2mqtt/linky`.**

- **No more energy thresholds + em dash for uninitialised values** — every "too small = N/A" floor is removed: the `EDF` chart's **1 kWh** N/A floor, the `EDF` stats' 1 kWh valid-day filter and the `Solaire` (Solar) averages' **0.1 kWh** floor. Any positive value now draws its real bar and counts toward the averages; **N/A strictly means a null day** (no data at all — a meter gap, an inverter that never reported; a null solar day now shows `N/A` instead of a silent zero-height bar). Separately, a figure that *exists but isn't initialised yet* renders as an **em dash with its unit kept**: the `EDF` banner shows `—kWh/j` / `HC —%` / `—€/j` before its first valid day, and in the bottom table the `HC` cell shows `—` until post-deploy days accumulate, a yesterday with no report shows `— kWh` (distinct from a real `0 Wh` day) and a missing average / `Talon` shows `—` (was `N/A`). Rendered golden regenerated (data golden byte-identical); no new environment variable.
- **`Alertes`: per-plug off-peak drift rule + `Cumulus` section renamed `Prises`** — the status board's `Cumulus` section becomes **`Prises`** (Plugs): it now appears as soon as **any** power sensor is configured and hosts every power-sensor rule (the existing cumulus rise/drop included). New red rule **`prise_hc_drop`**: a plug whose **last-9-days off-peak share** (`hc_pct`) fell by **≥ 10 points** vs the prior 28 days fires *Heures creuses {nom} en baisse {n}pts* (off-peak share of {name} dropping), costed at the **HP premium** on the shifted kWh (`avg_kwh × points × (PRICE_HP − PRICE_HC)` per day); if several plugs drift, only the **worst offender** shows (vertical space). It needs both periods' HC split, so on an existing deployment it stays **quiet for ~5 weeks** while post-deploy history accumulates. Threshold: `PRISE_HC_DROP_PTS` in `electricity/alerts.py`. Goldens regenerated (the seed now drifts the washer out of off-peak to exercise the rule); no new environment variable.
- **`EDF` bottom table: off-peak `HC` % column** — each power-sensor row gains an **`HC` column**: the share (%) of its **last 9 days'** consumption that fell inside the Linky off-peak windows (`HC_WINDOWS`, the same variable the EDF chart already uses) — handy to check a `Cumulus` really heats off-peak. The MQTT integrator now splits each power increment into a new `daily_power.hc_wh` column alongside the daily total (idempotent migration; **no new environment variable**). Days recorded **before** this feature have no HC split and are excluded from the ratio, so the `HC` cell stays **empty until new days accumulate** after deployment (the Talon row never shows one — the talon is a power level, not an energy bucket).
- **`EDF` bottom table: section-title header + tighter layout** — the table now opens with its own **column-title row above the separator line** (`Hier` — yesterday, `Moy.` — average, `HC`), drawn in the **same band as the `Solaire` (Solar) title** opposite so both sections share the same separator line; the EDF chart's baseline and day labels now **align with the `Eau` (Water) chart's** to its right. The redundant `hier` word disappears from the row units (`3.2 kWh hier` → `3.2 kWh`, `303 W hier` → `303 W` — the header carries that meaning now), names truncate at **13 characters** (was 33) with an ellipsis, and the columns are spread out for air — except the average and its trend, which read as one glued block. Goldens (data + render) regenerated; the preview also gains extra representative demo rows (`Machine à laver`, `Serveur`, `Salon`, `Imprimante 3D`) to exercise the fuller table.

## 2026-06-04

- **Power sensors: small consumptions shown in Wh, never dropped to `N/A`** — a power sensor's `kWh hier` (yesterday) and `kWh/j` (daily average) values now render **adaptively**: a figure below 1 kWh shows in **whole Wh** (e.g. `28 Wh hier`, `967 Wh/j`) instead of collapsing to `0.0 kWh` after the 1-decimal rounding — even though a real but tiny day still drew its sparkline bar. The **0.05 kWh average floor is also removed** for power sensors: every recorded day now counts toward the average (a day with no report stays excluded), so a low-power plug no longer shows `N/A`. That floor was meant for the Linky data (whose API can return garbage), not for trusted plug readings. Internally the slice exposes a numeric `avg_kwh` used for the row sort and the `Cumulus` alert money (no more parsing the display string). Goldens (data + render) regenerated; no new environment variable.
- **`EDF` bottom table sorted by consumption** — the rows under the `EDF` chart (the power sensors `Cumulus` / `Lave-linge` / `Salon` …) are now ordered **by descending daily average** (`kWh/j`) — the biggest consumer on top, the smallest at the bottom — instead of `POWER_SENSORS` config order. Sensors still without a recent average (`N/A`) sink to the bottom (keeping their relative config order), and the **`Talon` row stays last** in every case. Pure display ordering in the renderer (`_build_bottom_rows`): the data pipeline is untouched (`data.golden.json` unchanged), only the rendered golden was regenerated. Also fixes a stale reference in the render golden's `--update-golden` path (`db.get_cached_days` → `electricity.infrastructure.repository.get_cached_days`, left over from the domain-driven move). No new environment variable.
- **Domain-driven restructuring of `server/app/` (no behaviour change)** — the server is reorganised **by business domain** instead of by tech slice, with CQRS inside each domain. The `app/integrations/{linky,ecoflow,power,unifi,water,crypto}/` tree becomes five domains `app/{electricity,water,solar,network,crypto}/`, each split into a point of entry (`__init__.py`, the uniform `enabled/init_schema/start/attach/status` API), pure `rules.py`, `command.py` (writes), `query.py` (reads), its own `alerts.py`, and a private `infrastructure/` (`repository.py` + transport). `electricity` is the core (Linky) and absorbs the generic power sensors as an `electricity/power/` sub-domain (Cumulus, Lave-linge). Two transverse packages sit beside the domains: `app/module/` (ready-to-use infra — `db.connect()`, shared `format.py` helpers + the `AlertRule` descriptor) and `app/system/` (`config.py`, `scheduler.py`, and the golden **`tests/`**). `app/alerts.py` is now a thin cross-domain aggregator that collects each domain's rules; `app/registry.py` lists the core + optional domains the orchestrator iterates. `rendering/` stays pure display. The Docker files (`Dockerfile`, `docker-compose*.yml`, `.env.example`) move up from `server/infra/` to `server/`, and a new `server/pyproject.toml` points pytest at `app/system/tests` (still run `pytest` from `server/`). **Pure restructuring**: both goldens (`data.golden.json`, `display.golden.bin`) are byte-identical, no env var added or renamed, the CasaOS runtime is unaffected. CI updated (Docker build `file: server/Dockerfile`); the compose import URLs change (`…/main/server/docker-compose.yml` / `…casaos.yml`) and the local `.env` now lives at `server/.env`.
- **Power sensors: sum several topics under one label** — `POWER_SENSORS` entries that share the same display name are now **grouped into a single bottom-table row whose energy is the sum** of its topics (e.g. four plugs all named `Salon` → one `Salon` total with its own yesterday / daily-average / trend / 7-day sparkline). Each topic keeps its own MQTT listener and integrator (no shared state, no lock); the sum is computed at display time over the group's per-topic daily series. A lone sensor still stores under its slugified label (unchanged, **history preserved, no migration**); members of a multi-topic group get a per-topic-suffixed slug so they never collide. A day reported by **at least one** member is summed over the members present, so adding a plug to a group later doesn't blank its history. Declare a group by simply repeating the label: `POWER_SENSORS="zigbee2mqtt/prise_1:Salon;zigbee2mqtt/prise_2:Salon;zigbee2mqtt/cumulus:Cumulus"`. The `Alertes` `Cumulus` domain still resolves by label. Data golden regenerated (seeded a two-topic `Salon` group); no new environment variable.

## 2026-06-03

- **Wider name columns in the `EDF` bottom table and `Réseau` clients** — the name column of the table under the `EDF` chart gets more room (its `kWh hier` column starts further right), and the `Réseau` panel's client names are now truncated at **35** characters instead of 15, so longer device names (e.g. `MacBookPro Lamia`) show in full. The `EDF` table's sensor names also gain a 33-character truncation guard. Rendered golden regenerated; no new environment variable.
- **`GET /` browser preview implemented** — the documented `GET /` HTML preview now actually works: it returns an auto-refreshing HTML page embedding the dashboard as a PNG, served by a new `GET /preview.png` route (the 1360×480 RGB render that feeds the EPD converter). Previously only `/display` (the ESP32's binary buffer), `/status` and `/api/data` were wired, so opening the server in a browser returned a 404.
- **Bottom table: per-row 7-day sparklines + 5-column layout** — each row of the table under the `EDF` chart (the power sensors `Cumulus` / `Lave-linge` and the `Talon`) now ends with a **7-day sparkline** hugging the right edge: seven thin black bars for the last seven completed days (same axis as the `EDF` chart), normalised to that row's own max so it reads the metric's recent shape (a missing day leaves a gap). The row is regridded into **five columns** — name (left), `kWh hier` (yesterday, left), `kWh/j` (daily average, right), trend (left) and the sparkline (right) — so the averages and trends line up cleanly per column. Sparkline data reuses each slice's existing daily history (no new fetch, no new environment variable). Goldens (data + render) regenerated.
- **⚠️ Config-driven power sensors (breaking env change), replacing the `Cumulus` & `Lave-linge` slices** — the two were byte-identical power→energy slices (a Zigbee2MQTT/ESPHome device reporting only instantaneous power, integrated into daily kWh, shown as one bottom-table row) differing only in their env var, table and label. They're collapsed into **one generic slice driven by a single variable**: `POWER_SENSORS`, a `;`-separated list of `topic:Display Name` entries (the first `:` splits topic from label). Adding a new power sensor is now **a config line, no code**. Each entry gets its own MQTT listener + integrator, stores into a shared `daily_power(slug, …)` table (slug = slugified label) and renders one row (yesterday / daily-average / trend), in config order, above the always-shown `Talon` row. A one-time, idempotent DB migration copies the old `daily_cumulus` / `daily_washer` rows into `daily_power` under slugs `cumulus` / `lave-linge`, so **trend history is preserved as long as the labels stay `Cumulus` and `Lave-linge`**. The `Alertes` board's `Cumulus` domain (rise/drop rules) now reads the sensor labelled `Cumulus`; behaviour and layout are unchanged (the rendered golden is byte-identical). **On CasaOS: remove `CUMULUS_TOPIC` and `WASHER_TOPIC`, add `POWER_SENSORS="zigbee2mqtt/cumulus:Cumulus;zigbee2mqtt/washing_machine:Lave-linge"`** (keep those two labels to inherit the history). The shared `MQTT_*` broker config and the `Eau` (Water) slice are unchanged.
- **`Lave-linge` (washing machine) consumption + layout rework** — a new optional slice mirrors `Cumulus`: a Zigbee2MQTT smart plug reports only instantaneous power, integrated into daily kWh (no backfill), shown as a `Lave-linge` row in the bottom table (between `Cumulus` and `Talon`) with yesterday / daily-average / trend. Enable it with `WASHER_TOPIC` (plus the shared `MQTT_HOST`, see below). The dashboard layout is reworked at the same time: the **`EDF` consumption chart now fills the whole left column** (with the bottom table beneath it), and the **`Solaire` (Solar) chart moves under the `Eau` (Water) chart** in the center column, which splits at mid-height (`Eau` top, `Solaire` bottom). Goldens regenerated.
- **⚠️ Shared local MQTT broker config (breaking env change)** — the `Cumulus`, `Lave-linge` and `Eau` (Water) slices all talk to the **same local broker**, so the host/port/credentials are now configured **once** via `MQTT_HOST` / `MQTT_PORT` / `MQTT_USERNAME` / `MQTT_PASSWORD`; each slice keeps only its own `*_TOPIC`. A slice is enabled when `MQTT_HOST` **and** its topic are set (an empty `MQTT_HOST` disables all three). **On CasaOS: remove `CUMULUS_MQTT_HOST/PORT/USERNAME/PASSWORD` and `WATER_MQTT_HOST/PORT/USERNAME/PASSWORD`, add the new `MQTT_*` block, and set `CUMULUS_TOPIC` / `WATER_TOPIC` / `WASHER_TOPIC`** (the topics no longer have a default). EcoFlow's cloud broker is separate and unaffected.
- **`Talon` (baseline power): computed over a solar-free night window** — the talon (the home's permanent standby draw) is now the **P20 of the Linky load curve restricted to 23h–05h**, instead of the P5 over the full 24h. The Conso curve is grid draw (soutirage), already net of self-consumed solar, so an EcoFlow PowerStream's daytime injection used to crush the curve toward 0 and drag the talon **below** the home's real baseline; the night window is solar-free, so the reading is honest again. The percentile rises 5→20 to keep skipping the deepest dips over the ~12 night samples. A one-time `user_version` DB migration NULLs the old 24h talons so they re-fetch and recompute night-only on the next refresh — no action needed, no new environment variable. The panel layout is unchanged.
- **`Réseau` (Network): data-usage trend over the last 30 days** — the `Données hier/30j` (Data yesterday/30d) line now carries a ▲▼ trend comparing the **last 30 days to the prior 30** — whether the home used more or less data overall lately (neutral black arrow; more/less data isn't inherently good or bad). Computed straight from the daily WAN report (no DB, no backfill); the report fetch window grows 35→65 days to cover both windows, so the trend appears once ~60 days of history exist. Replaces the previous 7-day daily trend on that line. No new environment variable.
- **`Home` next-refresh time matches the device's real next wake** — when clock drift wakes the ESP a minute before a boundary (e.g. 09:59 for the 10:00 wake), the firmware skips that boundary and sleeps to the next one (12:00); the `Home` panel used to show the raw next boundary (`09:59 ► 10:00`) and now shows the device's real next wake (`09:59 ► 12:00`). New optional env var `SCREEN_WAKE_SKIP_MIN` (default 5) — keep it equal to the firmware's `sleep_min < 5` guard.
- **ESP32 firmware: boot diagnostics** — each boot logs its reset reason and wake cause over serial (timer wake vs a full power loss vs brownout), to tell a healthy 2 h timer wake apart from a power-supply issue (e.g. a host USB port cutting 5 V when it sleeps). Reflash to apply.
- **Documentation now fully in English** — all docs (`README.md`, `CHANGELOG.md`, `CLAUDE.md`) read in English; each on-screen French string keeps its literal but gets an English gloss (e.g. `Réseau` (Network), `Eau` (Water)), while the code's French UI labels are untouched (the screen stays French).

## 2026-06-02

- **`Home`: displayed time = real moment of the pull** — the left time of the `Home` panel (`Écran  HH:MM ► HH:MM`) is no longer the **refresh boundary** frozen at data-build time (≈`DATA_LEAD_MIN` before the boundary), but the **real moment of the `GET /display`** — when the ESP pulls the image — recomputed on every pull (with the next even-hour boundary on the right). Rendering now happens **on every pull** (no longer only when crypto is enabled); on a render error it falls back to the cached buffer. No environment variable; `build_dashboard_data` unchanged → goldens unchanged.
- **ESP32 firmware: guaranteed deep sleep + bounded retry** — every path now ends in a **deep sleep**: a PSRAM allocation failure no longer hangs awake forever in an infinite loop (`while(1)`), it sleeps and retries like the other errors. Failed cycles (WiFi/PSRAM/fetch) go through a **back-off retry** — up to `MAX_QUICK_RETRIES` (3) quick wakes (5 min) for a brief outage, then falling back to the full interval (2 h) to preserve the battery; the counter lives in **RTC memory** (survives deep sleep) and resets to 0 after a clean cycle. The **NTP** sync result is now checked and logged; with no valid clock the sleep lasts one **full interval** (instead of a hard-coded 1 h) and a later wake with NTP up realigns itself onto the even hours. New firmware constant `MAX_QUICK_RETRIES` — **reflash the ESP32** to enable.
- **Tree restructuring: `hardware/` vs `server/`** — clean split of the physical and server sides, root reduced to `README.md` + `CHANGELOG.md` (+ `CLAUDE.md`). The **ESP32 firmware** (`hardware/esp32-display/`), the **3D case** (`hardware/case/Dashboard.3mf`) and the **photo** (`hardware/device.jpg`) move under `hardware/`. The whole server moves under `server/`: the **package** `server/app/`, the **golden net** `server/tests/`, the **Docker infra** `server/infra/` (`Dockerfile` + `docker-compose*.yml` + `.env.example`), the **scripts** `server/scripts/` (`gen_preview.py` + `preview.png`) and the `requirements*.txt`. `server/` becomes the **Python import root**: `python -m app` and `pytest` run **from `server/`** (`app/` and `tests/` stay top-level packages, no internal import changed). CI updated (Docker build `context: server` + `file: server/infra/Dockerfile`; tests with `working-directory: server`). **Deployment**: no environment variable added or renamed — the CasaOS runtime (pre-built image) is unaffected; however the compose import URLs change (`…/main/server/infra/docker-compose.yml` and `…casaos.yml`), and the local `.env` now lives at `server/infra/.env`. Pure move (git history preserved), no rendering change — goldens unchanged.
- **Screen refresh every 2 h + server update aligned to it** — the ESP32 firmware no longer wakes at two fixed hours (8 h/17 h) but on a **clock-aligned interval** (`REFRESH_INTERVAL_MIN = 120` → 00:00, 02:00 … 22:00). On the server side, the loop no longer runs on a blind hourly cycle: it regenerates the buffer **`DATA_LEAD_MIN` minutes (10) before** each screen wake, so the ESP always pulls a render at most a few minutes old (`app/schedule.py`, the shared single source of truth). The `Home` panel drops its two lines for a **single line** — `Écran  14:00 ► 16:00` — showing the current screen-refresh time and the next, both derived from the same schedule. **Environment variables**: `REFRESH_INTERVAL` is replaced by `SCREEN_REFRESH_INTERVAL_MIN` (120, must match the firmware) and `DATA_LEAD_MIN` (10) — to update on the CasaOS deployment. Goldens regenerated.
- **Golden-master anti-regression net (`tests/`)** — before the architectural refactor, a **pytest** suite freezes a known input (seeded SQLite DB + frozen clock) and compares the output bit-for-bit against committed references: **data layer** (`build_dashboard_data()` → `tests/fixtures/data.golden.json`, portable, covers the orchestrator + the DB-backed slices + the alerts) and **render layer** (`render_dashboard()` → `png_to_epd_buffer()` → `tests/fixtures/display.golden.bin`, the 163,200-byte EPD buffer; actual/golden/diff PNGs in `/tmp` on a mismatch). Run `pytest -q` (must stay green), re-baseline with `--update-golden`. CI **GitHub Actions** (`.github/workflows/tests.yml`) on push + PR. `Pillow` is now **pinned** (rendering is sensitive to FreeType, which differs by about 5% of the buffer macOS↔Linux): the data layer is byte-exact everywhere (strict guard), the render layer is strict locally and a simple smoke test in CI (`GOLDEN_TOLERANCE`). No deployment environment variable added.
- **`Alertes` (Alerts) panel (top-left gutter)** — under the `Home` panel, a **per-domain status board** (`EDF`, `Eau` — Water, `Solaire` — Solar, `Réseau` — Network, `Cumulus`, `Crypto`) built from the already-computed daily trends. Each monitored domain is a **section title** with its separator, followed by **plain-language messages** (rendered in French on screen; English in parentheses): a problem in **red** (« Forte hausse de consommation 15%/j » — sharp rise in consumption, « Fuite d'eau probable 240 L » — probable water leak, « Panneaux solaires déconnectés ? » — solar panels disconnected?, « Latence réseau élevée » — high network latency…) or a **positive** note in **black** (« Forte production solaire » — strong solar production, « Belle baisse de consommation » — nice drop in consumption, « Bot devant le hold » — bot ahead of buy-and-hold…). Each line adds, when computable, its **financial impact** — `dépense`/`économie` (spend/save) in €/day (EDF consumption, off-peak hours, standby, cumulus, water), € (solar production) or `gain`/`manque` (gain/shortfall) in $ for **Crypto** (the strategy's gain estimated via the **alpha** × the invested amount). A healthy domain shows « Rien à signaler » (nothing to report). Hard-coded thresholds (tunable in `app/alerts.py`), no new environment variable (reuses `PRICE_HP`/`PRICE_HC`).
- **`Home` panel (top-left gutter)** — a `Home` section title showing the **day + time of the last update** and the **time of the next**, in the free space to the left of the packed columns.
- **Zero bars = line** — in the `Solaire` (Solar) and `Eau` (Water) charts, a **zero** value now draws a **baseline** (like the `N/A` marker) instead of nothing, so a day at 0 stays visible.
- **`Réseau` (Network): rolling "month" + sections named by SSID** — the "data" total of the `Réseau` panel is no longer calendar-based (it dropped to ~0 on the 1st of the month) but **rolling over the 30 complete days ending yesterday** — always a full, day-to-day comparable window; the line is relabelled `hier/30j` (yesterday/30d). The two client mini-tables now carry the **real SSID name** (`UNIFI_SSID_MAIN`/`UNIFI_SSID_IOT`, e.g. `Atchoum` / `Iotchoum`) as a header, instead of the generic `Perso`/`IoT` (falls back to the generic if the variable is empty).
- **`Réseau` (Network): top-4 clients + "aujourd'hui" (today) marker** — the client mini-table of the `Réseau` panel goes from top-3 to **top-4** by traffic, and each network header carries a **« · aujourd'hui »** (today) marker (e.g. `Perso · aujourd'hui … 4 clients`) noting that the shown traffic is each client's current-session rx+tx. The main network (Perso) is rendered first; if screen height is short, the last line of the IoT network (smallest traffic) is trimmed by the existing degradation.
- **Columns packed to the right** — the `Solaire` (Solar)/`EDF` and `Eau` (Water) columns are shifted right to sit against (8 px gap) the right-anchored `Crypto`/`Réseau` (Network) column, so the empty space ends up at the far left of the screen instead of being stuck between the `Eau` and `Crypto` columns.

## 2026-06-01

- **Solar "today" bar fix (real root cause)** — today's solar bar was stuck at `0` even though production was accumulating correctly in the database. The read-back query used an **exclusive** upper bound set to *today*, so `WHERE date < today` dropped today's own row and fell back to 0. The bound is now *tomorrow*, matching the water slice. (The earlier keep-alive/echo and threshold changes were genuine improvements but not the cause of this symptom — the `today` bar had never worked since it was introduced.)

- **Solar "today" bar fix** — today's solar bar showed **N/A** despite live production. The MQTT listener subscribes to the same topic it publishes its 60s keep-alive request to, so the broker echoed that request back; sharing the heartbeat's `cmd_func/cmd_id` but carrying an empty payload, it decoded to a phantom **0 W** sample that claimed the whole interval since the last real reading at zero watts, collapsing the day's integral to ~0. Payload-less control echoes are now ignored (a genuine night-time 0 W heartbeat still carries a full payload, so it is unaffected), and the listener no longer subscribes to the `…/property/get` topic it publishes to, removing the echo at its source.
- **Solar chart shows every yield** — the solar chart no longer hides small days behind an `N/A` floor: any value, however small (down to 0), now draws a bar. The `N/A` threshold still applies to the EDF consumption chart only — useful for small PV setups whose daily yield can sit below the old 0.05 kWh floor.
- **Water meter consumption** — optional `Eau` (Water) chart in the top-center space, between the Solar chart and the Crypto panel: the last **9 days** of water use as daily-litres bars, with a title showing the average **L/day** (and trend), the month-to-date **m³** and its **€** cost. An ESPHome wM-Bus reader publishes the meter's cumulative index (m³) over MQTT; the dashboard derives daily litres by **index difference** (not power integration, unlike Cumulus) — no backfill, history starts at first connection. A day with no reading shows **N/A**, including today until its first frame arrives. Enabled by setting `WATER_MQTT_HOST`.
- **Solar & water "today" bar** — the Solar and Water charts now end on **today** (rightmost bar labelled `Auj.`) instead of yesterday, so the current day's accumulation is visible. The EDF consumption chart still ends on yesterday (no same-day data).

## 2026-05-31

- **Solar chart precision** — the value above each bar of the solar production chart now shows two decimals (e.g. `0.06` instead of `0.1`), so small daily yields stay readable. The EDF consumption chart below keeps its one-decimal format.

## 2026-05-30

- **UniFi network panel** — optional `Réseau` (Network) panel in the bottom-right (under the crypto grid): internet (ISP name + health %) and Wi-Fi quality in the title, then latency, Wi-Fi signal score, data usage (yesterday/month), and the top-3 clients per SSID with per-network client counts (main Wi-Fi first, then IoT). All fields are mapped from the gateway's aggregated-dashboard payload: ISP from `wan_routability_info`, health from the WAN downtime history, latency from the WAN activity history, Wi-Fi from per-standard satisfaction (weighted by station count), month usage summed from the daily WAN report, and top clients by their rx+tx traffic. ▲▼ trends (7-day average from a `daily_unifi` snapshot, no backfill) on internet/Wi-Fi, latency and data usage (neutral, black). Talks to the local UniFi gateway (cookie auth, self-signed cert). Enabled by setting `UNIFI_PASSWORD`.
- **Crypto grid warning markers** — the grid snapshot now flags the bot's last placement cycle: a full-yellow ▲ is drawn right after the Y-axis price label of every skipped level (insufficient funds, half-spacing or max-orders), mirroring the iOS grid badges. Only the marked level's dashed line is shortened to make room — the other lines keep their full width — and markers from a cycle older than 5 minutes are dropped.
- **Solar talon coverage** — the solar title now ends with a `Talon … %` item: the share of the house's baseline-power (talon) energy the solar production covers, computed from the 9-day averages (average daily PV kWh over the talon's daily energy, `avg_w × 24h`). Always shown — falls back to `Talon N/A` until the talon is known — and positioned to the left of the `Total … kWh` group (then the `€`).
- **Talon (baseline power)** — the dashboard now computes the house's baseline power (the P5 of each day's 30-min Linky load curve, in W — the permanent floor: fridge, box, standby), persisted in `daily_consumption.talon_w` and backfilled from the load-curve history.
- **Bottom table (Cumulus + Talon)** — the bottom strip became a 3-column table (name · yesterday · average + trend) under a single top separator line: the name and yesterday columns are left-aligned, the average+trend column is right-aligned. The Talon row is always shown (core Linky data), with the Cumulus row stacked above it when that integration is enabled.
- **2px screen margin** — the whole dashboard is now inset 2px from every e-paper edge instead of bleeding edge-to-edge.
- **Internal refactor (no behavior change)** — the loose root modules became an `app/`
  package organized as vertical slices: each integration (`linky`, `ecoflow`, `cumulus`,
  `crypto`) is a self-contained folder owning its config, storage, transport (in tech
  subfolders `mqtt/`/`proto/`/`graphql/`/`api/`), integrator and render panel, wired
  through an `OPTIONAL` registry. Dead code removed (`templates/`, `send_to_esp32`). The
  server now runs with `python -m app`. Fonts co-located under `app/rendering/fonts/`,
  `Dashboard.3mf` moved to `hardware/`, and the local runtime dir is now `.data/`.

- **Crypto profit grouping** — the Crypto banner now groups the bot's results behind a `Profits` label: the signed `%` return and the `±$` amount on one line (red when negative), keeping the portfolio value as a separate segment.
- **Crypto alpha** — the Crypto banner now shows an `α` segment: the bot's excess return over buy-and-hold (all-time bot return minus `holdReturnPercent`), black when ahead, red when behind.
- **Crypto grid snapshot chart** — under the Crypto banner (top-right): the grid price levels with left labels and dashed lines, the 7-day price line, and a "now" marker dot with the live current price. Rendered black & white. Reuses the existing `CRYPTO_API_URL`/`CRYPTO_API_TOKEN` (fetched live on the ESP32's `/display` pull).
- **`scripts/gen_preview.py`** — regenerates `docs/preview.png` from the local DB history + live crypto, for UI review.
- **Cumulus banner** — now shows **yesterday's** completed daily consumption (`kWh hier`) instead of today's partial total, and moves to a full-width row at the very **bottom of the screen, below the EDF chart** (which shrinks slightly to make room).
- **Chart split** — the solar chart is slightly shorter so the EDF chart gets a bit more height.

## 2026-05-29

- **Chart title labels** — the solar and consumption titles now lead with a `Solaire` (Solar)/`EDF` label (matching the `Crypto`/`Cumulus` banners), with tighter spacing between each value and its trend.
- **Solar money saved** — the EcoFlow title now shows the euros saved over the period (production total valued at the peak/HP grid price), next to the `kWh total`.
- **Cumulus consumption trend** — the water-heater banner now shows a trend on its daily average (last 9 days vs the previous 4 weeks; ▲ in red = consuming more).
- **Edge-to-edge layout** — removed the screen margins on all four sides so the charts and banners fill the full display; the spacing between the two stacked charts is preserved.

## 2026-05-28

- **Cumulus (water-heater) consumption** — optional inline title-style banner (top-right, under the crypto one) showing the water-heater's daily kWh and recent daily average. The Zigbee contactor (Legrand 412171) reports only instantaneous power, so daily kWh are integrated over time from its Zigbee2MQTT power topic (no historical backfill). Enabled by setting `CUMULUS_MQTT_HOST`.
- **Crypto-bot stats banner** — optional inline title-style banner in the top-right (same look as the chart titles): a `Crypto` label, the bot's % return (red when negative), signed profit, portfolio value and a `SANDBOX` badge. Fetched over GraphQL when the ESP32 pulls `/display`, with graceful fallback to the cached buffer. Enabled by setting `CRYPTO_API_URL` (and optionally `CRYPTO_API_TOKEN`).

- **EcoFlow PowerStream solar production** — optional daily solar production chart in the top half of the screen (full-black bars), above the consumption chart. Reads the inverter's reported PV power over the EcoFlow app MQTT broker (kept alive by a periodic get-quota request) and integrates it into daily kWh totals; shows the last 9 completed days (N/A until data accumulates), daily average and trend. History starts at first connection (no backfill). Enabled by setting `ECOFLOW_EMAIL`/`ECOFLOW_PASSWORD`/`ECOFLOW_DEVICE_SN`.
- **Bundled Arial font** — the renderer now ships Arial in the repo and uses it everywhere, so Docker output is pixel-identical to local renders (previously Docker fell back to Liberation Sans, which looked less sharp at small sizes)

## 2026-05-27

- **ESP32 serial configuration** — WiFi and server URL configured via serial monitor instead of captive portal
- **NTP-based refresh schedule** — display updates at 8:00 and 17:00 (CET/CEST) instead of every hour
- **Pillow bitmap renderer** — pixel-perfect text rendering using FreeType with `fontmode='1'`, replacing Playwright/Chromium
- **N/A days handling** — days with less than 1 kWh are shown as "N/A" and excluded from stats
- **Stats filtering** — trend calculations ignore incomplete data days

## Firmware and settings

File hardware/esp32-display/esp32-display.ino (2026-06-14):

#include <WiFi.h>
#include <HTTPClient.h>
#include <time.h>
#include <esp_system.h>
#include <esp_sleep.h>

#include "nvs_config.h"
#include "DEV_Config.h"
#include "EPD_10in85g.h"

// Survives deep sleep (reset only on power loss), so we can bound how often we
// wake to retry after a failure instead of pinging every 5 min forever.
RTC_DATA_ATTR static uint32_t failCount = 0;
RTC_DATA_ATTR static uint32_t bootCount = 0;

// Deep sleep after a failed cycle: quick 5-min retries for a brief outage
// (router rebooting…), then back off to the normal interval to save battery.
// Never returns.
static void deepSleepRetry(const char *reason) {
    failCount++;
    uint64_t us = (failCount <= MAX_QUICK_RETRIES)
                      ? RETRY_SLEEP_US
                      : (uint64_t)REFRESH_INTERVAL_MIN * 60ULL * 1000000ULL;
    Serial.printf("%s — retry #%lu, deep sleep %llus\n",
                  reason, (unsigned long)failCount, (unsigned long long)(us / 1000000ULL));
    Serial.flush();
    esp_deep_sleep(us);
}

static String serialReadLine() {
    String line = "";
    while (true) {
        if (Serial.available()) {
            char c = Serial.read();
            if (c == '\n' || c == '\r') {
                if (line.length() > 0) {
                    Serial.println();
                    return line;
                }
            } else {
                line += c;
                Serial.print(c);
            }
        }
        delay(10);
    }
}

static bool checkResetCommand() {
    Serial.println("Type 'reset' within 3s to reconfigure...");
    unsigned long start = millis();
    String input = "";
    while (millis() - start < BOOT_WAIT_MS) {
        if (Serial.available()) {
            char c = Serial.read();
            if (c == '\n' || c == '\r') {
                input.trim();
                if (input.equalsIgnoreCase("reset")) return true;
                input = "";
            } else {
                input += c;
            }
        }
        delay(10);
    }
    return false;
}

static String buildDisplayUrl(const String &serverUrl) {
    String url = serverUrl;
    if (url.endsWith("/")) url += "display";
    else if (!url.endsWith("/display")) url += "/display";
    // Battery-autonomy telemetry: the server logs these to bound each charge
    // cycle. bootCount/failCount survive deep sleep and reset only on power loss;
    // reset_reason 1=POWERON (recharged / first boot → new cycle), 8=DEEPSLEEP
    // (our timer wake → same cycle), 9=BROWNOUT.
    url += "?boot=" + String(bootCount)
         + "&reason=" + String((int)esp_reset_reason())
         + "&fail=" + String(failCount);
    return url;
}

static bool fetchDisplayBuffer(const String &serverUrl, uint8_t *buf) {
    HTTPClient http;
    String url = buildDisplayUrl(serverUrl);
    Serial.printf("Fetching: %s\n", url.c_str());

    http.begin(url);
    http.setTimeout(30000);

    int httpCode = http.GET();
    if (httpCode != 200) {
        Serial.printf("HTTP error: %d\n", httpCode);
        http.end();
        return false;
    }

    WiFiClient *stream = http.getStreamPtr();
    uint32_t bytesRead = 0;

    // Overall deadline: a stalled server (connection open, no more bytes) would
    // otherwise spin here forever — the screen freezes and the battery drains.
    unsigned long start = millis();
    while (bytesRead < DISPLAY_BUFFER_SIZE && http.connected()
           && (millis() - start) < FETCH_DEADLINE_MS) {
        size_t available = stream->available();
        if (available > 0) {
            size_t toRead = min((size_t)(DISPLAY_BUFFER_SIZE - bytesRead), available);
            size_t got = stream->readBytes(buf + bytesRead, toRead);
            bytesRead += got;
        } else {
            delay(10);
        }
    }

    http.end();
    Serial.printf("Received %lu / %lu bytes\n", (unsigned long)bytesRead, (unsigned long)DISPLAY_BUFFER_SIZE);

    return bytesRead == DISPLAY_BUFFER_SIZE;
}

static bool syncNtp() {
    configTzTime("CET-1CEST,M3.5.0,M10.5.0/3", "pool.ntp.org");
    Serial.print("NTP sync");
    for (int i = 0; i < 20; i++) {
        delay(500);
        Serial.print(".");
        struct tm t;
        if (getLocalTime(&t, 0)) {
            Serial.printf(" OK: %02d:%02d\n", t.tm_hour, t.tm_min);
            return true;
        }
    }
    Serial.println(" FAILED");
    return false;
}

static uint64_t computeSleepUs() {
    struct tm now;
    if (!getLocalTime(&now, 0)) {
        // No clock (NTP never succeeded): can't align to a boundary. Sleep one
        // full interval unaligned; a later wake with NTP up re-aligns by itself.
        Serial.println("No valid time — sleeping one full interval (unaligned)");
        return (uint64_t)REFRESH_INTERVAL_MIN * 60ULL * 1000000ULL;
    }

    int cur_min = now.tm_hour * 60 + now.tm_min;

    // Wake on the next clock-aligned interval boundary (0h, 2h, 4h… for 120 min).
    int sleep_min = REFRESH_INTERVAL_MIN - (cur_min % REFRESH_INTERVAL_MIN);

    if (sleep_min < 5) sleep_min += REFRESH_INTERVAL_MIN;

    Serial.printf("Now: %02d:%02d, next refresh in %dh%02dm\n",
                  now.tm_hour, now.tm_min, sleep_min / 60, sleep_min % 60);

    return (uint64_t)sleep_min * 60ULL * 1000000ULL;
}

void setup() {
    Serial.begin(115200);
    delay(500);
    Serial.println("\n=== Linky Dashboard ===");
    bootCount++;
    // Boot diagnostics for a headless deep-sleep device: reset_reason 1=POWERON
    // (power was cut — e.g. host USB sleeping), 8=DEEPSLEEP (our timer woke us),
    // 9=BROWNOUT; wakeup_cause 4=TIMER.
    Serial.printf("Boot #%lu — reset_reason=%d wakeup_cause=%d failCount=%lu\n",
                  (unsigned long)bootCount, (int)esp_reset_reason(),
                  (int)esp_sleep_get_wakeup_cause(), (unsigned long)failCount);

    if (checkResetCommand()) {
        clearConfig();
        Serial.println("Configuration cleared.");
    }

    String ssid, pass, serverUrl;
    bool hasConfig = loadConfig(ssid, pass, serverUrl);

    if (!hasConfig) {
        Serial.println("\nNo configuration found. Starting setup...\n");

        Serial.print("WiFi SSID: ");
        ssid = serialReadLine();

        Serial.print("WiFi Password: ");
        pass = serialReadLine();

        Serial.printf("Server URL [%s]: ", DEFAULT_SERVER_URL);
        serverUrl = serialReadLine();
        if (serverUrl.length() == 0) serverUrl = DEFAULT_SERVER_URL;

        saveConfig(ssid, pass, serverUrl);
        Serial.println("\nConfiguration saved.");
    }

    Serial.printf("Connecting to WiFi: %s\n", ssid.c_str());

    bool connected = false;
    for (int attempt = 1; attempt <= WIFI_MAX_RETRIES; attempt++) {
        Serial.printf("Attempt %d/%d...\n", attempt, WIFI_MAX_RETRIES);
        WiFi.mode(WIFI_STA);
        WiFi.begin(ssid.c_str(), pass.c_str());

        unsigned long start = millis();
        while (WiFi.status() != WL_CONNECTED && (millis() - start) < WIFI_TIMEOUT_MS) {
            delay(250);
            Serial.print(".");
        }
        Serial.println();

        if (WiFi.status() == WL_CONNECTED) {
            connected = true;
            break;
        }
        WiFi.disconnect(true);
        delay(1000);
    }

    if (!connected) {
        deepSleepRetry("WiFi failed");
        return;
    }

    Serial.printf("Connected. IP: %s\n", WiFi.localIP().toString().c_str());

    if (!syncNtp()) {
        Serial.println("WARNING: NTP failed — schedule may be unaligned this cycle");
    }

    uint8_t *buf = (uint8_t *)ps_malloc(DISPLAY_BUFFER_SIZE);
    if (!buf) {
        WiFi.disconnect(true);
        deepSleepRetry("PSRAM allocation failed");
        return;
    }

    if (!fetchDisplayBuffer(serverUrl, buf)) {
        free(buf);
        WiFi.disconnect(true);
        deepSleepRetry("Fetch failed");
        return;
    }

    DEV_Module_Init();
    EPD_10in85g_Init();
    Serial.println("Rendering...");
    EPD_10in85g_Display(buf);
    EPD_10in85g_Sleep();

    free(buf);

    failCount = 0;  // clean cycle — back to the normal aligned schedule
    uint64_t sleepUs = computeSleepUs();

    WiFi.disconnect(true);
    DEV_Module_Exit();

    Serial.printf("Deep sleep...\n");
    Serial.flush();
    esp_deep_sleep(sleepUs);
}

void loop() {
}

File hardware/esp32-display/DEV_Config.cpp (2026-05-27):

/*****************************************************************************
* | File      	:   DEV_Config.c
* | Author      :   Waveshare team
* | Function    :   Hardware underlying interface
* | Info        :
*----------------
* |	This version:   V1.0
* | Date        :   2020-02-19
* | Info        :
#
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
******************************************************************************/
#include "DEV_Config.h"

void GPIO_Config(void)
{
    pinMode(EPD_PWR_PIN,  OUTPUT);
    pinMode(EPD_BUSY_PIN,  INPUT);
    pinMode(EPD_RST_PIN , OUTPUT);
    pinMode(EPD_DC_PIN  , OUTPUT);
    
    pinMode(EPD_SCK_PIN, OUTPUT);
    pinMode(EPD_MOSI_PIN, OUTPUT);
    pinMode(EPD_CS_M_PIN , OUTPUT);
    pinMode(EPD_CS_S_PIN , OUTPUT);

    digitalWrite(EPD_PWR_PIN , HIGH);
    digitalWrite(EPD_CS_M_PIN , HIGH);
    digitalWrite(EPD_CS_S_PIN , HIGH);
    digitalWrite(EPD_SCK_PIN, LOW);
}

void GPIO_Mode(UWORD GPIO_Pin, UWORD Mode)
{
    if(Mode == 0) {
        pinMode(GPIO_Pin , INPUT);
	} else {
		pinMode(GPIO_Pin , OUTPUT);
	}
}
/******************************************************************************
function:	Module Initialize, the BCM2835 library and initialize the pins, SPI protocol
parameter:
Info:
******************************************************************************/
UBYTE DEV_Module_Init(void)
{
	//gpio
	GPIO_Config();

	//serial printf
	Serial.begin(115200);

	// spi
	// SPI.setDataMode(SPI_MODE0);
	// SPI.setBitOrder(MSBFIRST);
	// SPI.setClockDivider(SPI_CLOCK_DIV4);
	// SPI.begin();

	return 0;
}

/******************************************************************************
function:
			SPI read and write
******************************************************************************/
void DEV_SPI_WriteByte(UBYTE data)
{

    for (int i = 0; i < 8; i++)
    {
        if ((data & 0x80) == 0) digitalWrite(EPD_MOSI_PIN, GPIO_PIN_RESET); 
        else                    digitalWrite(EPD_MOSI_PIN, GPIO_PIN_SET);

        data <<= 1;
        digitalWrite(EPD_SCK_PIN, GPIO_PIN_SET);     
        digitalWrite(EPD_SCK_PIN, GPIO_PIN_RESET);
    }
}

UBYTE DEV_SPI_ReadByte()
{
    UBYTE j=0xff;
    GPIO_Mode(EPD_MOSI_PIN, 0);
    for (int i = 0; i < 8; i++)
    {
        j = j << 1;
        if (digitalRead(EPD_MOSI_PIN))  j = j | 0x01;
        else                            j = j & 0xfe;
        
        digitalWrite(EPD_SCK_PIN, GPIO_PIN_SET);     
        digitalWrite(EPD_SCK_PIN, GPIO_PIN_RESET);
    }
    GPIO_Mode(EPD_MOSI_PIN, 1);
    return j;
}

void DEV_SPI_Write_nByte(UBYTE *pData, UDOUBLE len)
{
    for (int i = 0; i < len; i++)
        DEV_SPI_WriteByte(pData[i]);
}


void DEV_Module_Exit(void)
{
    digitalWrite(EPD_PWR_PIN , LOW);
    digitalWrite(EPD_RST_PIN , LOW);
}

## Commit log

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2026-05-27 feat(esp32): add firmware with captive portal and pull mode
    Complete ESP32 firmware for XIAO ESP32-S3:
    - Captive portal WiFi provisioning (AP "Linky-Setup")
    - Setup instructions rendered on e-paper with bitmap font
    - Config stored in NVS (survives reboots)
    - Pull mode: GET /display from server
    - Deep sleep 1 hour between refreshes
    - Waveshare epd10in85g driver (4-color, dual-panel SPI)
    - Auto-clear config after 3 failed WiFi attempts
    [DEV_Config.cpp, DEV_Config.h]
2026-05-27 feat(esp32): working Waveshare 10.85" (G) example with XIAO ESP32S3
    Official Waveshare EPD_10in85g demo adapted for XIAO ESP32S3:
    - Pin remapping for XIAO (GPIO 10-14 unavailable, used by flash/PSRAM)
    - BUSY timeout to prevent infinite hangs
    - Serial init fix for USB CDC
    - Requires arduino-cli with PSRAM=opi flag
    XIAO pin mapping: RST=D0, DC=D1, CS_M=D2, BUSY=D3, PWR=D4,
    CLK=D8, DIN=D9, CS_S=D10
    Build: arduino-cli compile --fqbn "esp32:esp32:XIAO_ESP32S3:PSRAM=opi"
    [DEV_Config.cpp, DEV_Config.h, esp32-display.ino]
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2026-05-27 feat(esp32): replace test sketch with serial-configured WiFi pull mode
    Production firmware for XIAO ESP32S3:
    - Serial monitor config: WiFi SSID, password, server URL stored in NVS
    - HTTP GET /display to fetch 163,200-byte EPD buffer from Linky server
    - Deep sleep 1 hour between refreshes, 5 min on failure
    - Type 'reset' within 3s of boot to reconfigure
    - Remove unused GUI_Paint, fonts, ImageData (~1.3 MB)
    [esp32-display.ino]
2026-05-27 feat(esp32): NTP sync with scheduled refresh at 8h and 17h
    Replace fixed 1-hour deep sleep with NTP-based scheduling.
    ESP32 syncs time via pool.ntp.org (CET/CEST) after WiFi connect,
    then computes sleep duration until next target hour (8:00 or 17:00).
    Add Pillow-based bitmap renderer for pixel-perfect e-paper output.
    [esp32-display.ino, renderer.py]
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2026-05-28 fix(renderer): bundle Arial so Docker output matches local render
    Docker fell back to Liberation Sans (Arial absent on Linux), which
    rendered less sharp at 12-13px in bitmap mode. Ship Arial in the repo
    and point the renderer at it so output is pixel-identical everywhere.
    [renderer.py]
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2026-05-28 feat(crypto): show crypto stats banner, refresh on /display
    Draw a title-style banner (same look as the chart titles) in the empty
    top-right space: a Crypto label, % return (red when negative), profit and
    portfolio value, plus a SANDBOX badge. Data is fetched fresh when the ESP32
    pulls /display (it wakes ~2x/day) and the buffer re-rendered, with Linky and
    solar staying on the hourly cache; any failure falls back to the cached buffer.
    [renderer.py]
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2026-05-30 feat(cumulus): show yesterday's kWh in a full-width banner below the EDF chart
    Move the cumulus banner out of the top-right into a left-aligned, full-width
    row below the EDF (consumption) chart, with its separator above the text. The
    value is now yesterday's completed daily total instead of today's partial one.
    The solar chart is shortened slightly so the EDF chart gains a bit of height.
    [renderer.py]
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2026-05-30 refactor: move python modules into app/ package (lift-and-shift)
    Flat root modules become a proper package, with no behavior change:
    - server.py -> app/server.py
    - renderer/converter -> app/rendering/
    - *_client.py -> app/integrations/{linky,ecoflow,crypto,cumulus}.py
    - proto/ -> app/integrations/proto/
    New: app/__main__.py (`python -m app`), app/config.py (REPO_ROOT, FONTS_DIR, VERSION).
    Path fixes: fonts + .version resolved via config.REPO_ROOT; proto import made
    relative; Dockerfile CMD -> python -m app; gen_preview.py imports updated.
    [renderer.py]
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2026-05-30 refactor(rendering): co-locate fonts under app/rendering/
    The Arial fonts are a rendering asset used only by the renderer, so move fonts/
    into app/rendering/fonts/ and resolve the path relative to the renderer module.
    Drops FONTS_DIR from config.py (no longer a global concern).
    [renderer.py]
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2026-05-30 feat(rendering): bottom table (Cumulus + Talon) with 2px screen margin
    Replace the single Cumulus banner with a bottom table below the EDF chart: a
    3-column grid (name | yesterday | average+trend), one row per metric. The Talon
    row is always shown (core Linky); the Cumulus row stacks above it when enabled.
    Name and yesterday columns are left-aligned at fixed thirds, the average+trend
    column is right-aligned to the table edge, under a single 1px top separator.
    The whole dashboard is inset 2px from every e-paper edge (global MARGIN via
    CHART_LEFT/CHART_TOP/CHART_BOTTOM). gen_preview applies pending schema
    migrations before reading so it works against an older dev DB.
    [renderer.py]
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2026-05-30 feat(crypto): warning markers on the grid for skipped levels
    Mirror the iOS GridSnapshotCard badges: fetch the last placement cycle's
    skippedLevels (placementStatus) alongside the grid query and draw a small
    full-yellow ▲ right after the Y-axis price label of each skipped level.
    Covers all skip kinds (insufficient-funds, half-spacing, max-orders).
    - Stale guard: skips from a cycle older than 5 min are dropped, as on iOS.
    - Only the marked level's dashed line is shortened to make room for its
    marker; the other grid lines keep their full width.
    [renderer.py]
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2026-05-30 fix(unifi): map Réseau panel to the real gateway payload
    The aggregated-dashboard payload from the UCG Ultra has a different shape
    than the code assumed, so latency, month usage and the top-client traffic
    all resolved to their defaults (0). Re-map every field to the real paths:
    - ISP name: wan_routability_info[0].isp_name
    - ISP health %: fraction of internet.health_history samples without downtime
    - latency: average avg_latency_ms over wan_activity WAN history
    - Wi-Fi %: wifi_technology satisfaction, weighted by station count
    - month usage: summed from the daily.gw report (dashboard has no monthly counter)
    - top clients: rx_bytes + tx_bytes (active-clients has no usage_bytes)
    Drop the Vit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
    [renderer.py]
2026-06-01 feat: ajoute la conso d'eau (graphe + MQTT) facon EDF
    Nouvelle integration water/ : se connecte au broker MQTT, lit l'index cumulatif
    du compteur (m3) publie par l'ESPHome sur watermeter/index_m3, et en derive la
    conso quotidienne par DIFFERENCE d'index (pas d'integration, contrairement a
    cumulus) + total mensuel + cout.
    - water/ : listener MQTT (parse float brut ou JSON) + slice
    enabled/init_schema/start/attach/status ; table daily_water (diff d'index).
    - renderer : _draw_water_chart, graphe a barres dedie dans le quadrant
    haut-droite (a droite du solaire) + bandeau Eau (L/j, m3 mois, EUR).
    - db : get_cached_water / upsert_water.
    - .env.example : bloc WATER_* (topic watermeter/index_m3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
    [renderer.py]
2026-06-01 feat(water): place Eau chart top-center, today bar + 9 days
    - Move the water "Eau" chart into the empty top-center space, right after the
    Solar chart (small 8px gap), so it no longer overlaps the Crypto panel.
    - Solar & Water charts now end on today (rightmost bar labelled "Auj.") instead
    of yesterday, so the day's accumulation is visible. EDF stays on yesterday.
    - Water: show N/A for today until its first reading (no carry-forward 0), and
    extend the chart from 7 to 9 days (aligned with Solar).
    - docs: document the water meter (README + CHANGELOG entry) and declare WATER_*
    in docker-compose.casaos.yml.
    - chore: scrub the server LAN IP and the crypto API token from the repo
    (README,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
    [renderer.py]
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2026-06-01 feat(solar): drop the N/A floor and stop subscribing to the keep-alive topic
    Two follow-ups to the keep-alive echo fix:
    - Hardening: the listener no longer subscribes to the .../property/get topic it
    publishes the keep-alive request to, so the broker never echoes our own
    payload-less request back as a phantom 0 W heartbeat. PV data still arrives on
    get_reply and the device broadcast. The decode_pv_power guard stays as
    defense-in-depth. Verified live: data keeps flowing without the subscription.
    - The solar chart drops its N/A floor entirely (was 0.05 kWh): every value, down
    to 0, now draws a bar so small PV yields are never hidden. The N/A threshold
    now applies to the EDF consum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
    [renderer.py]
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2026-06-02 feat(dashboard): left-gutter Home panel + per-domain Alertes status board
    Fill the empty top-left gutter with two stacked sections.
    Home: a "Home" section title showing the day + time of the last refresh and
    the time of the next one (refresh cycle + REFRESH_INTERVAL).
    Alertes: a new trend-based engine (app/alerts.py) turns the daily values
    already computed by each integration into a status board — one section per
    monitored domain (EDF/Eau/Solaire/Réseau/Cumulus/Crypto). Each domain is a
    section title; under it, plain-language notes — problems entirely red,
    positive highlights entirely black — with the figure (bold number, glued
    regular unit) and, where derivable, the financial impac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
    [renderer.py]
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2026-06-02 firmware(esp32): refresh the screen every 2h instead of fixed 8h/17h
    Replace the two fixed wake hours (REFRESH_HOUR_1/2) with a single
    clock-aligned interval (REFRESH_INTERVAL_MIN = 120) so the panel wakes at
    00:00, 02:00 … 22:00. The < 5 min guard now rolls to the next boundary
    instead of clamping, avoiding a double refresh near a boundary.
    [esp32-display.ino]
2026-06-02 feat(dashboard): align data refresh to the screen schedule + show it on Home
    The server now regenerates the buffer DATA_LEAD_MIN (10 min) before each
    screen-refresh boundary instead of on a blind hourly cycle, so the ESP32
    always pulls a render that is only minutes old. New app/schedule.py holds
    the shared boundary math (mirrors the firmware's clock-aligned interval).
    The Home panel drops its two rows for a single line — "Écran 14:00 ► 16:00"
    — reporting the screen refresh this image is for and the next one, both
    derived from the same schedule. (► U+25BA; U+25B8 isn't in the bundled Arial.)
    Goldens regenerated on the Mac; pytest green at tolerance 0.
    [renderer.py]
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2026-06-02 firmware(esp32): always deep-sleep on failure + bounded retry backoff
    Three robustness fixes so the device always returns to low-power deep sleep:
    - PSRAM alloc failure no longer hangs awake forever in while(1); it deep-sleeps
    and retries like the other error paths.
    - syncNtp()'s result is now checked and logged; computeSleepUs falls back to one
    full interval (was a fixed 1h) when no clock is available, so the ~2h cadence
    holds and a later NTP-up wake re-aligns by itself.
    - Failed cycles (WiFi/PSRAM/fetch) go through deepSleepRetry(): quick 5-min
    retries for a brief outage, then back off to the full interval to save battery.
    An RTC_DATA_ATTR counter survives deep sleep and resets o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
    [esp32-display.ino]
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2026-06-03 firmware(esp32): log reset reason & wakeup cause at boot
    Print a one-line boot diagnostic (boot count, reset_reason, wakeup_cause,
    failCount) so a headless deep-sleep device can be told apart at a glance:
    timer wake (reset_reason=8/wakeup_cause=4) vs a full power loss
    (reset_reason=1, e.g. the host USB port cutting 5V on sleep) vs brownout.
    Used to confirm the wake path is healthy and isolate power-supply issues.
    [esp32-display.ino]
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2026-06-03 feat(washer): washing-machine slice + Eau-over-Solaire layout rework
    Add a "Lave-linge" slice mirroring cumulus: it integrates the smart-plug's
    reported power (Z2M `power`, no kWh counter) into daily_washer and shows a
    yesterday / average / trend row in the bottom table (between Cumulus and Talon).
    Uses the shared MQTT broker + WASHER_TOPIC.
    Rework the layout: the EDF consumption chart now fills the whole left column
    (with the bottom table beneath it), and the solar chart moves under the Eau
    chart in the center column, which splits at mid-height (Eau top, Solaire bottom).
    _draw_chart gains a region_left arg so it can render in either column.
    Seed daily_washer and enable the slice in the go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
    [renderer.py]
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2026-06-03 fix(layout): refine the center column — tighten Eau/Solaire, size EDF to it
    Tighten the gap between the Eau and Solaire charts in the center column (drop the
    extra DIVIDER_GAP insets around the mid-height split), and size the EDF chart in
    the left column so its bottom table's separator line aligns exactly with the Solar
    section title's separator line opposite it (its day labels sit just above that
    shared divider). Goldens regenerated.
    [renderer.py]
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2026-06-03 feat(table): 5-column bottom table with per-row 7-day sparklines
    The bottom table (power sensors + Talon) becomes a 5-column grid:
    name (left), kWh hier (left), kWh/j (right), trend (left, narrow), and a 7-day
    sparkline column hugging the right edge. Each row carries a `spark` series
    (last complete days, ending yesterday — same axis as the EDF chart), drawn as
    7 thin black bars normalised per row; missing days leave a gap. The sparkline
    column is a touch wider than the bars so the graph keeps a small margin on each
    side, and the trend column is narrow so the kWh/j+trend+spark cluster stays
    compact on the right.
    Column anchors are width fractions so the kWh/j values and trends line up per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
    [renderer.py]
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2026-06-03 feat(layout): widen name columns in EDF bottom table and Réseau clients
    - EDF bottom table: BOTTOM_COL_HIER 0.24 → 0.32 (more room for the name column)
    + truncate sensor names at 33 chars (_short_name)
    - Réseau panel: client name truncation 15 → 35 chars
    - preview fixture: full client names to reflect the wider limit
    - CHANGELOG + render golden updated
    [renderer.py]
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2026-06-04 feat(electricity): sort EDF bottom table by descending daily average
    Power-sensor rows under the EDF chart are now ordered by descending
    daily average (kWh/j) — biggest consumer on top — instead of config
    order, with N/A sensors sinking to the bottom and the Talon row always
    last. Pure display ordering in the renderer (_build_bottom_rows); the
    data pipeline is untouched so data.golden.json is unchanged, only the
    rendered golden regenerated.
    Also fix a stale reference in the render golden's --update-golden path
    (db.get_cached_days -> electricity.infrastructure.repository), left over
    from the domain-driven move.
    [renderer.py]
2026-06-04 fix(power): show small plug consumption in Wh, drop the NA floor
    The bottom-table "hier"/avg columns formatted every plug figure as
    `f"{kwh:.1f}"`, so any real day under 0.05 kWh collapsed to "0.0 kWh"
    even though the sparkline still drew a (correct) bar. The 0.05 kWh
    average floor also forced low-power plugs to "N/A". Both were meant for
    Linky data (whose API can be wrong), not for trusted plug readings.
    - format_energy_kwh(): adaptive unit — whole Wh below 1 kWh, else kWh.
    - power: every recorded day counts toward the average (no floor); expose
    numeric avg_kwh for sorting + Cumulus alert money (no more string parse).
    - renderer: per-row dynamic unit + sort by avg_kwh.
    [renderer.py]
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2026-06-05 feat(rendering): whole-percent trends everywhere
    Every trend (EDF stats, talon, power sensors, solar, water, network)
    now rounds to a whole percent at computation, and _trend() rounds
    defensively at display — no more one-decimal trends like ▼6.5%. A
    sub-0.5% drift now rounds to 0 and renders as the em dash. Alert
    figures inherit the integer values. Goldens and preview regenerated.
    [renderer.py]
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2026-06-05 fix(rendering): tariff dot drawn as a real 10px circle
    The Arial "●" glyph was small and lumpy after thresholding; the dot is
    now rasterised 4x oversize, downscaled and re-thresholded, centered on
    the banner's cap height.
    [renderer.py]
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2026-06-06 feat(electricity): intraday power profile under each EDF bar
    A bar-wide (28px) mini bar-graph under each EDF chart column shows that
    day's mean PAPP per 30-min slot (tic_samples), squeezed between the bars'
    baseline and the day labels. 48 slots resample to one 1px column per
    pixel; missing slots leave gaps; heights normalise to the 9-day window's
    global max so day profiles compare to each other. Today's strip fills
    live; past days accumulate as the Lixee history grows (no backfill).
    - repository.get_papp_profiles(): one query bucketing papp_va by date+slot
    - rules.build_core attaches each shown day's `intraday` profile (pure,
    profiles fetched in query.build_core over the same calendar win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
    [renderer.py]
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2026-06-06 feat(electricity): sparkline-style bars for the intraday strip
    The intraday profile under each EDF bar was 28 1px columns — too thin to
    read on e-paper. Resample the 48 half-hour slots to 6 four-hour buckets
    drawn with the bottom-table sparkline geometry (3px bars, 2px gaps,
    6×5-2 = 28 = BAR_WIDTH). Heights stay normalised to the window's global
    max, now computed on the bucketed means so the tallest bar reaches the
    full strip height. Empty buckets still leave gaps.
    [renderer.py]
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2026-06-08 feat(electricity): Home tariff lines show HC/HP windows as ranges
    Replace the single 'last switch per period' tariff line with two lines, one
    per period, each showing its last completed window as 'HH:MM ► HH:MM' (same
    arrow style as the Écran schedule line). Windows are learned live from the
    meter's PTEC transitions — a window is recorded when the transition that ends
    it arrives — so multi-window-per-day schedules render correctly without
    relying on the HC_WINDOWS config.
    current_tariff() now returns {period, hc, hp} (each a (start, end) tuple or
    None); _attach_tariff emits a list of {period, start_text, end_text} lines.
    Tests, golden masters and the preview generator updated accordi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
    [renderer.py]
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2026-06-09 feat(plants): new Zigbee soil-sensor domain with a Plantes gutter panel
    A new optional domain (server/app/plants/), config-driven like the power
    sub-domain via a single env var PLANTS_SENSORS = "topic:Name[:threshold];..."
    — one MQTT listener per plant, add/remove plants without code. Each plant is a
    two-line card in the left gutter, stacked under Home (Home -> Plantes ->
    Alertes, gaps tightened to pack closer):
    - Line 1 (title): name + a red water-drop icon when it needs watering + a red
    battery icon when its battery is low, with a 7-day soil-moisture sparkline at
    the right edge.
    - Line 2: uniform pairs "hum 45% temp 27° lum 76" (soil moisture, temperature,
    illuminance).
    Wateri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
    [renderer.py]
2026-06-09 feat(home): tighten vertical rhythm of the gutter sections
    The left-gutter column (Home / Plantes / Alertes and the alert sub-sections) read
    too airy. Trim the per-section header padding (title->separator 8->5, separator->
    content 6->4 on Home/Plantes; title_h+4->+3 and sep+5->+4 on the alert sections),
    the alert inter-section gap (6->2) and the inter-panel gaps (4->2). Sections pack
    noticeably closer while the separators stay legible. Golden + preview regenerated.
    [renderer.py]
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2026-06-09 feat(home): a touch more space between the gutter sections
    The previous pass over-tightened; nudge the inter-section gaps back up (inter-panel
    2->5, alert inter-section 2->5) for a balanced rhythm — sections breathe again
    without returning to the original airy spacing. Header padding stays tight. Golden
    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
    [renderer.py]
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2026-06-09 fix(rendering): uniform title-band height across the left column
    Home/Plantes/Alerts used a tighter title-to-separator gap (+5/+3) than the
    chart sections (+8); align them all on +8 so every section title sits the
    same height. Re-baselined the render golden and the preview.
    [renderer.py]
2026-06-10 fix(plants): scale moisture sparkline to the absolute 0-100% range
    The 7-day moisture spark normalised each bar to the plant's own weekly
    max, so a near-flat series (or a bone-dry plant) always drew full-height
    bars. Moisture is an absolute percentage: scale bars to 0-100 (clamped),
    keeping the 1px tick for present days and gaps for missing ones.
    Render golden re-baselined (only the Plantes sparklines differ).
    [renderer.py]
2026-06-10 fix(rendering): leave a gap for zero/missing sparkline values
    Previously every zero (or quiet intraday slot) drew a 1px floor tick.
    Hide them instead: a None or zero bucket now leaves a gap, both in the
    bottom-table sparklines and the EDF/Eau/Solaire intraday strips. The
    plants moisture sparkline is intentionally untouched (0% is a real
    bone-dry reading, not missing data).
    [renderer.py]
2026-06-10 fix(firmware): bound the /display body read loop with a 60s deadline
    A stalled server (connection open, no more bytes) made fetchDisplayBuffer
    spin forever — available() stays 0, http.connected() stays true and the
    30s HTTP timeout only covers active reads. The device then hung with the
    screen frozen until power-cycled. Cap the loop at FETCH_DEADLINE_MS and
    fall through to the existing deepSleepRetry path.
    [esp32-display.ino]
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2026-06-14 feat(battery): track ESP32 autonomy from /display pull telemetry
    The firmware now appends its RTC bootCount, reset reason and fail count as
    query params on the GET /display pull. A new optional `battery` domain logs
    each pull into battery cycles (a run on one charge, bounded by power-on
    events), and the Home panel shows "jours depuis la dernière charge" with
    average / record autonomy on /status. No extra sensor.
    - firmware: buildDisplayUrl appends ?boot&reason&fail
    - server: /display parses query params and calls a generic record_pull hook
    on enabled optional domains
    - battery domain: cycle detection (power-on = new cycle, deep-sleep = extend),
    with a boot-reset fallback when the reset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
    [esp32-display.ino, renderer.py]
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2026-06-14 feat(alerts): group all alerts under a single Alertes header
    The left-gutter status board gave each active domain its own bold title
    and 1px separator, burning vertical space in headers. Active items now
    list under one Alertes header (same order: most problems first, red
    before black positive notes); per-domain titles are gone, freeing room.
    Render golden re-baselined, preview regenerated.
    [renderer.py]
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2026-07-03 style(rendering): restore the uniform 13px bold panel titles
    Revert the 16px panel-title type scale (45a6c25): titles go back to the
    same 13px bold as the values, dropping the mixed-size baseline-align
    machinery. Keep the Réseau separator on the shared _title_sep_y metric.
    [renderer.py]
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2026-07-03 feat(solar): autonomy figure replaces the talon-coverage ratio
    The Solaire banner now shows the metric that matters for a solar home:
    the share of total consumption the panels covered (Auton. 42%). The
    Linky measures grid import net of self-consumed PV, so total consumption
    = grid + PV and autonomy = PV / (grid + PV), summed over the complete
    days both charts share (model: all PV self-consumed — no export
    measurement, micro-inverter sized below the base load; a 0.0 PV day is
    treated as a data gap, not a sunless day).
    The old 'Talon 111%' only related production to the night base load; it
    goes away (the talon keeps its own bottom-table row). Goldens
    re-baselined, preview regenerated.
    [renderer.py]
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
